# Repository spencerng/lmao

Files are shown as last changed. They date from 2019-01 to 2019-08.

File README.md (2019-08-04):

# Laundry Manager and Optimizer

The Laundry Manager and Optimizer was envisioned as an Internet of Things hamper that recognizes the laundry symbols (instructions) on clothing tags. It then sorts clothing articles into one of four sections so users can easily wash the right types of clothes together, thus preventing wear-and-tear.

Built by [Spencer Ng](https://github.com/spencerng) and [Kevin Tang](https://github.com/icevin) for their senior capstone project at the Middlesex County Academy for Science, Mathematics, and Engineering Technologies. [The project's prototype](https://devpost.com/software/load-optimization-assistance-device) was a Top 30 Hack winner at PennApps XVIII.

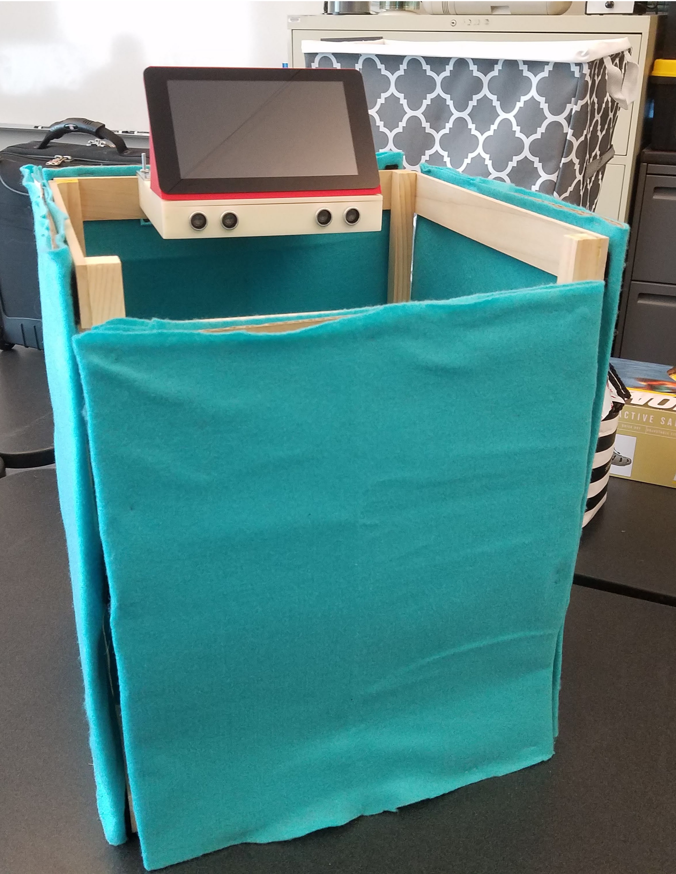
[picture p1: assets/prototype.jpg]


### Project specifications

**Hardware used**

* 3D-printed base and lid
* Ultrasonic sensors
* Raspberry Pi 3
* 7" touchscreen
* Raspberry Pi Camera Module V2
* Wood and cardboard frame for hamper prototype

**Software**

* Python 3 application developed for Raspberry Pi
* GUI built on Qt framework
* Symbol recognition done with OpenCV

### Additional links

* [Product manual with diagrams/screenshots](./assets/manual.pdf)
* [Initial design review with specifications](./assets/design-review.pdf)
* STL files
  * [Base](./assets/base.stl)
  * [Lid](./assets/lid.stl)
  * [Conceptual model](./assets/conceptual-model.stl)

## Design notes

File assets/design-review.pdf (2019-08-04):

# Laundry Manager and Optimizer (LMaO) Marking Period 1 Design Review & Deliverables

### Spencer Ng & Kevin Tang Electrical & Computer Engineering Technologies Middlesex County Academy

## Contents

1 Senior project proposal agreement | 2
2 Conceptual diagrams | 4
3 Block diagram | 10
4 Design specifications | 11
5 Gantt Chart | 14
6 Roles and responsibilities | 17
7 Bill of materials | 18
8 Risk factors and contingency plans | 19
9 Testing plans | 19
10 Patent search findings | 20
11 Acknowledgements and resources | 20

1

# l I I c1=t,sMET

L\tAD:E I!\ TrlE t:s.. t\

### Senior Project lnnovation

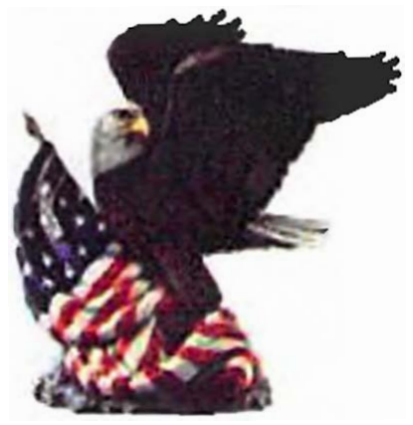
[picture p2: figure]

# lnvention title: Laundry Manager and Optimizer (LMaO) Instructor Name: Mr. E. Paterno Instructor Approval: f e Student Name: Spencer Ng Student Signature: ------- .h Student Name: Kevin Tang Student Signature: &w: ______ _ Problem to be addressed:

# Team No. 6

Date: to/ev/(¡ --¡,+---,---=---

# Date: / (J /¡ (J / l f

# Date: _1 (J

....J

/
'----

1 u---'-

/ 1
_

# ( __ _

Laundry tags convey important washing instructions for clothes in the form of standardized,

# universal laundry symbols. However, this system fails to accommodate users who may not have the time or knowledge to decode the symbols. Consequently, many individuals use the wrong cleaning products or machine settings, leading to unnecessary washing, energy

waste, and wear-and-tear.

lnnovation description: The Laundry Manager and Optimizer (LMaO) is an Internet of Things (loT) smart laundry system that scans the laundry symbols on tags using computer vision and machine learning technology. This information is uploaded to the Cloud, where it communicates with other LMaOs in the same household or living facility, allowing groups to Manage and Organize

loads quickly and determine the correct settings for each of their loads.

# lnnovation features: The LMaO can: - Sean ISO laundry care symbols on standard laundry tags usíng computer vision and machine learning technology

Senior project proposal agreement | Laundry Manager and Optimizer

- Connect multiple LMaOs for any user group to the cloud via Wi-Fi
- Automatically alert users when the attached hamper is full
- Provide user-friendly laundering instructions vía a touchscreen
- Reduce energy consumption while optimizing laundry loads

## lnnovation operation:

To place an article of clothing into the LMaO, the user locates the tag and places it in the scanning area of the LMaO. The LMaO then identifies the symbols and prompts the user via the touchscreen to drop the article into one of severa! hamper areas. When the LMaO(s) have reached capacity, or if the user indicates they wish to do their laundry (via the touchscreen of any linked LMaO), the user is provided with the recommended washer and dryer settings for each load and a list of articles of clothíng to wash.

## Required technologies:

Hardware | Software
Raspberry Pi (Single Board Computer) | OpenCV with Python
Raspberry Pi Camera | TensorF/ow
Raspberry Pi Touchscreen | Google C/oud P/atform (Firebase Server)
AC Power Circuitry | Wi-Fi

## Proposed customers:

- Washing or dryíng machine companies who wish to promete energy efficiency and assist users in determining the correct settings to use far their machines

lnvention title: Laundry Manager and Optimizer (LMaO)

Instructor lnitials: ----'-' --"'-/( _? __ _ Student lnitials: __ 5._._l\J_---- 1 Student lnitials: __ 'Í.._,_T ____ _ | Team No. 6
| Date: __ l

# ,1-0_/_v/Í_/_cY __

| Date: _1 ()) --1

, Ú
| ,_.. /_ fY ....:c.. /¡_ ( __ Date: __L ó..;_/_¹ l_· _( ,_i __ _
Senior project proposal agreement | Laundry Manager and Optimizer

## 7” Touchscreen Display

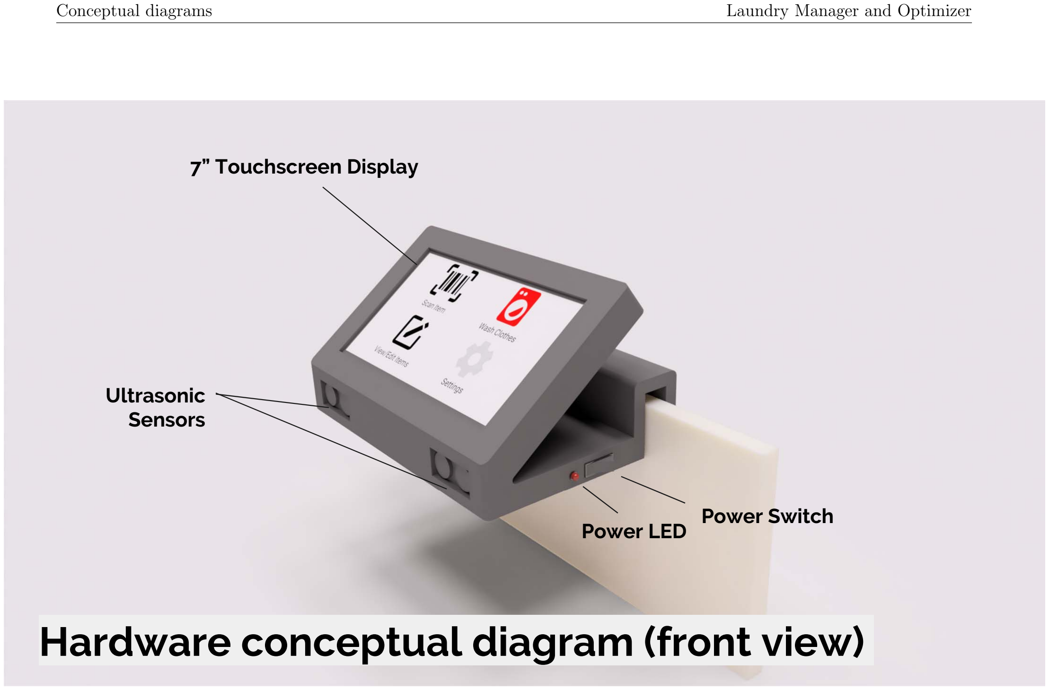
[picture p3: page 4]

Hardware conceptual diagram (front view).

## Power Switch Power LED

## Ultrasonic Sensors

Conceptual diagrams | Laundry Manager and Optimizer

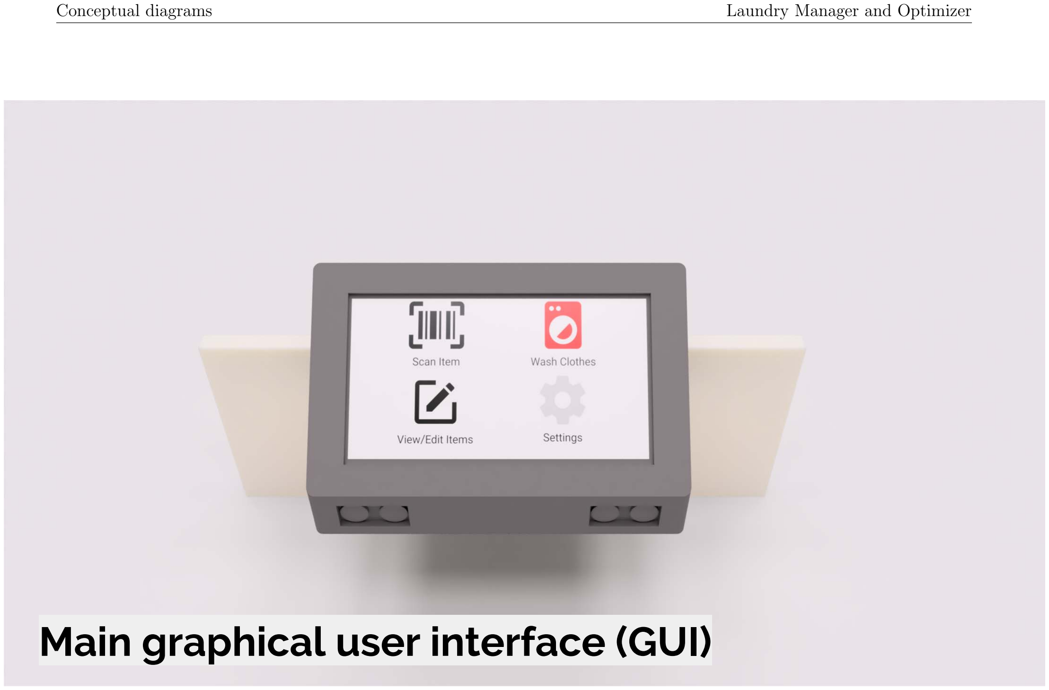
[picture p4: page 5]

# Main graphical user interface (GUI)

Conceptual diagrams | Laundry Manager and Optimizer

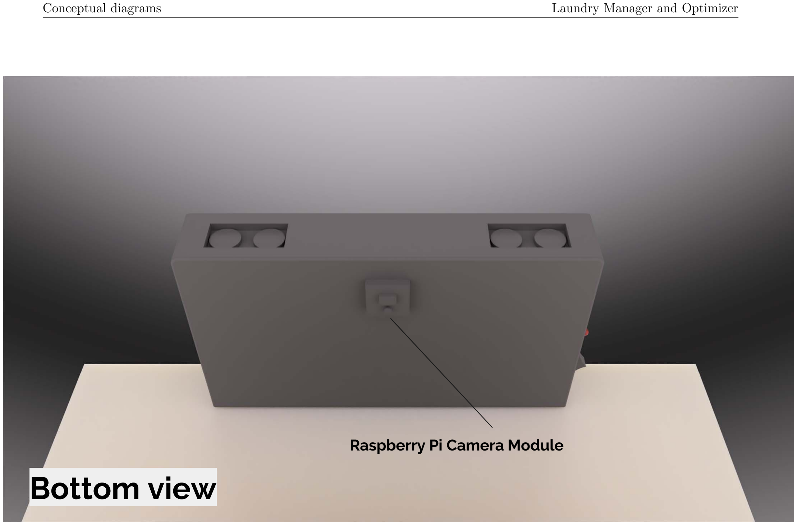
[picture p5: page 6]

# Bottom view

## Raspberry Pi Camera Module

Conceptual diagrams | Laundry Manager and Optimizer

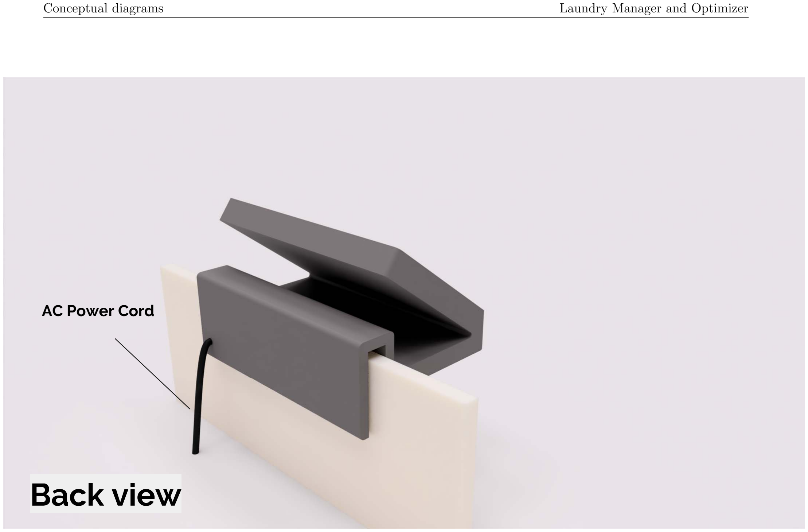
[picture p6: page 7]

# Back view

## AC Power Cord

Conceptual diagrams | Laundry Manager and Optimizer

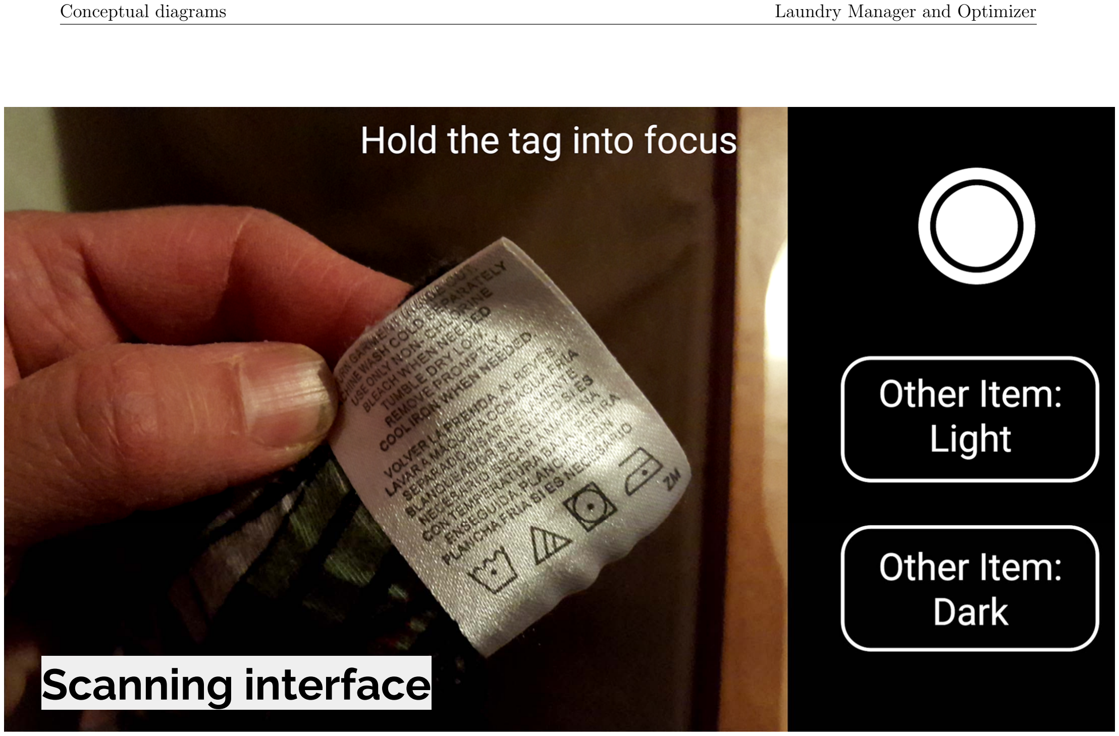
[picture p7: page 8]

# Scanning interface

Conceptual diagrams | Laundry Manager and Optimizer

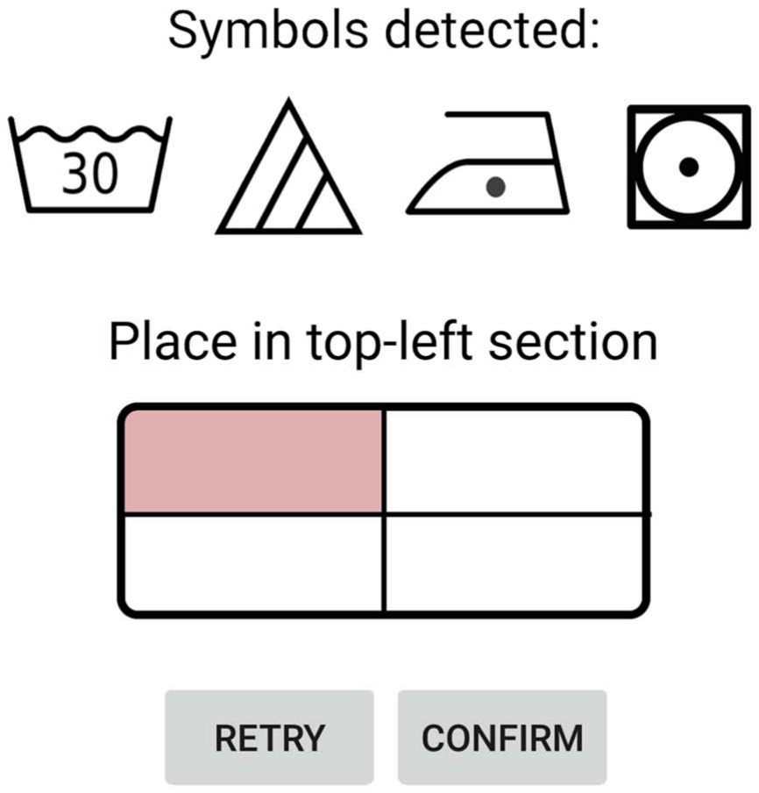
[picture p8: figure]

# Confirmation screen

Conceptual diagrams | Laundry Manager and Optimizer

## Block Diagram

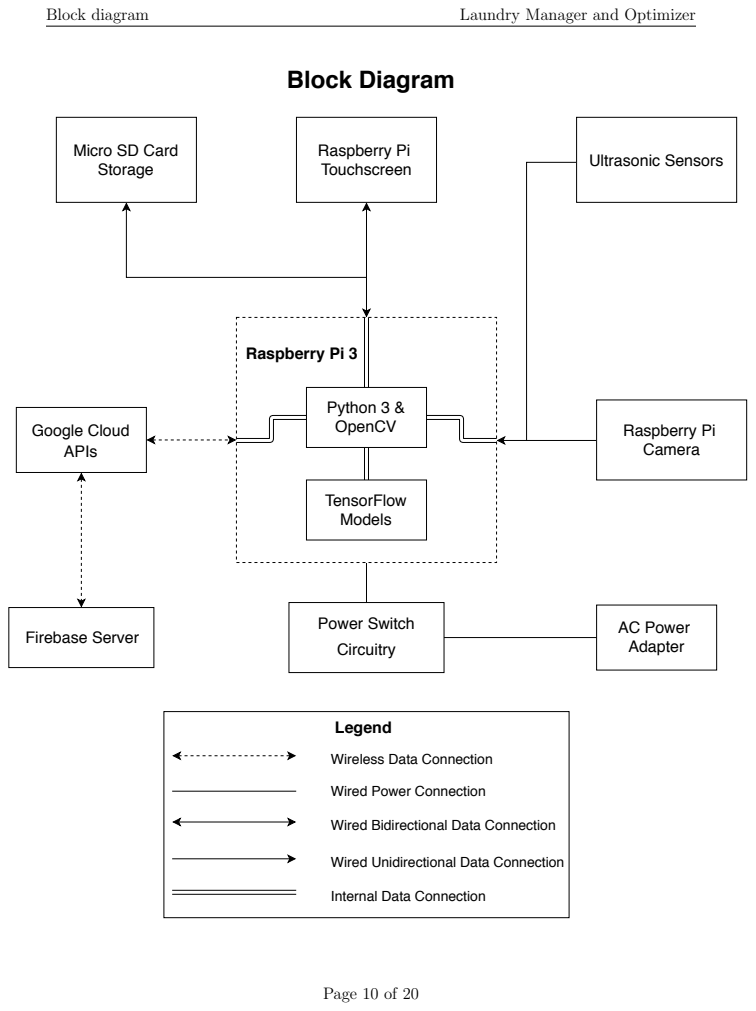
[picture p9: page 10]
Raspberry Pi Camera; Firebase Server; Google Cloud APIs; AC Power Adapter; Power Switch; Circuitry; Raspberry Pi 3; Legend; Python 3 & OpenCV; TensorFlow Models; Block diagram; Laundry Manager and Optimizer

Micro SD Card
Storage

Ultrasonic Sensors Raspberry Pi
Touchscreen

Wireless Data Connection

Wired Power Connection

Wired Bidirectional Data Connection

Wired Unidirectional Data Connection

Internal Data Connection

Functional descriptions and requirements | Laundry Manager and Optimizer

## 4 Design specifications

### 4.1 Hardware requirements

Raspberry Pi 3

- Single-board computer that drives the camera, touchscreen, ultrasonic sensors, and power circuitry
- Reads from and writes to external micro SD card storage
- Connects to cloud services via Wi-Fi

Ultrasonic sensors

- Send distance data to Raspberry Pi via GPIO pins
- Consistently and accurately detect when any section of the hamper is full
- Has 3 mm accuracy and 300 cm range

Raspberry Pi touchscreen

- Displays graphical user interface
- Allows users to interact with menu items
- Connects to Raspberry Pi via DSI port
- Has 7” screen size and 800 x 480 px resolution for large, easy-to-use interface

Raspberry Pi camera

- Connects to Raspberry Pi via CSI port
- Clearly scans and focuses on laundry symbols when are held 1-3” underneath
- Has 8 MP resolution

Micro SD card

- Contains 32 GB of storage for operating system, Python scripts, and TensorFlow models

Power circuitry

- Wakes and shuts down the Raspberry Pi via a slide switch
- Contains RBG LED indicator that turns green when powered on, red when off
- Located on a 2-layer printed circuit board, approximately 1” x 2”

AC power adapter

- Converts 120V AC power to 5V DC to power the Raspberry Pi via micro USB

Functional descriptions and requirements | Laundry Manager and Optimizer

### 4.2 Software requirements

Python 3 & OpenCV

- Boots into an easy-to-navigate material design GUI created with the Tkinter library

– Contains submenus for tag scanning, washing loads, settings, and viewing/editing items

- Scanning submenu opens camera feed with a button to scan items

– Displays recognized symbols for the user to confirm

– Directs users to drop clothing article in the correct section, based on color and machine wash settings

– Contains manual override for socks and underwear; prompts user for color

- Settings submenu contains user account management (create account/change pass-word), LMaO nickname, and washer/dryer information (database with information on all models from major brands)
- View/edit submenu allows users to modify the number of items in the hamper
- Prompts users to do their laundry when any section of the hamper is detected as full

– Ultrasonic sensors detect objects within 14” (length of hamper) for a period of at least one (1) minute

- Wash submenu instructs users to remove and wash articles from each section separately, making note of special instructions (ironing a shirt in a load of T-shirts, hand wash, dry clean, etc.)

– Groups clothing with similar or identical washing requirements into a single wash load

– Combines clothes from linked LMaOs for optimization, as necessary

– Satisfies the washing requirements of at least 90% of the items in a load

– Provides instructions pertinent to the user’s washer and dryer model

- OpenCV library interfaces with stored TensorFlow models and detects presence of laundry symbols via contours and image filtering

TensorFlow models

- Trained with a set of over 200 close-up, labeled laundry symbol images
- Recognize machine wash, bleach, tumble dry, and ironing symbols with at least 90% accuracy when given a series of close-up, focused images of standard laundry tags

Functional descriptions and requirements | Laundry Manager and Optimizer

Firebase server

- Syncs with all LMaOs connected via Wi-Fi every five (5) minutes or when LMaOs are powered on
- Stores user account information: username and hashed/salted passwords
- Provides a list of all LMaOs linked a particular user accounts, identified by user-provided nickname
- Stores a list of clothing located in each section of an LMaO and the laundry symbols on their tags
- Updates when an item is scanned and placed into the hamper of the LMaO
- Deletes items from the database after they are washed

### 4.3 Mechanical requirements

LMaO packaging

- Contains Raspberry Pi, touchscreen, camera, ultrasonic sensors, AC adapter cord, and power switch circuitry in a 3D-printed box

– Touchscreen and ultrasonic sensors face outward, toward opposite edge of hamper

– Power switch printed circuit board soldered to the side of Raspberry Pi and is accessible by users

– AC adapter cord extends outward from the back

– Camera faces downward, into laundry hamper

- Held together by interlocking parts, Velcro, and screws and can withstand mild shaking
- Clamps onto the back edge of the laundry hamper without additional support
- Provides sufficient ventilation so the Raspberry Pi does not overheat

Laundry hamper

- Contains four (4) compartments of equal size for ease-of-use when removing clothes for different loads
- Supports the weight of the LMaO packaging on at least one (1) top edge
- Requires no additional support to stand up
- Approximately 14” x 14” x 23” in size with an open top; easily transportable

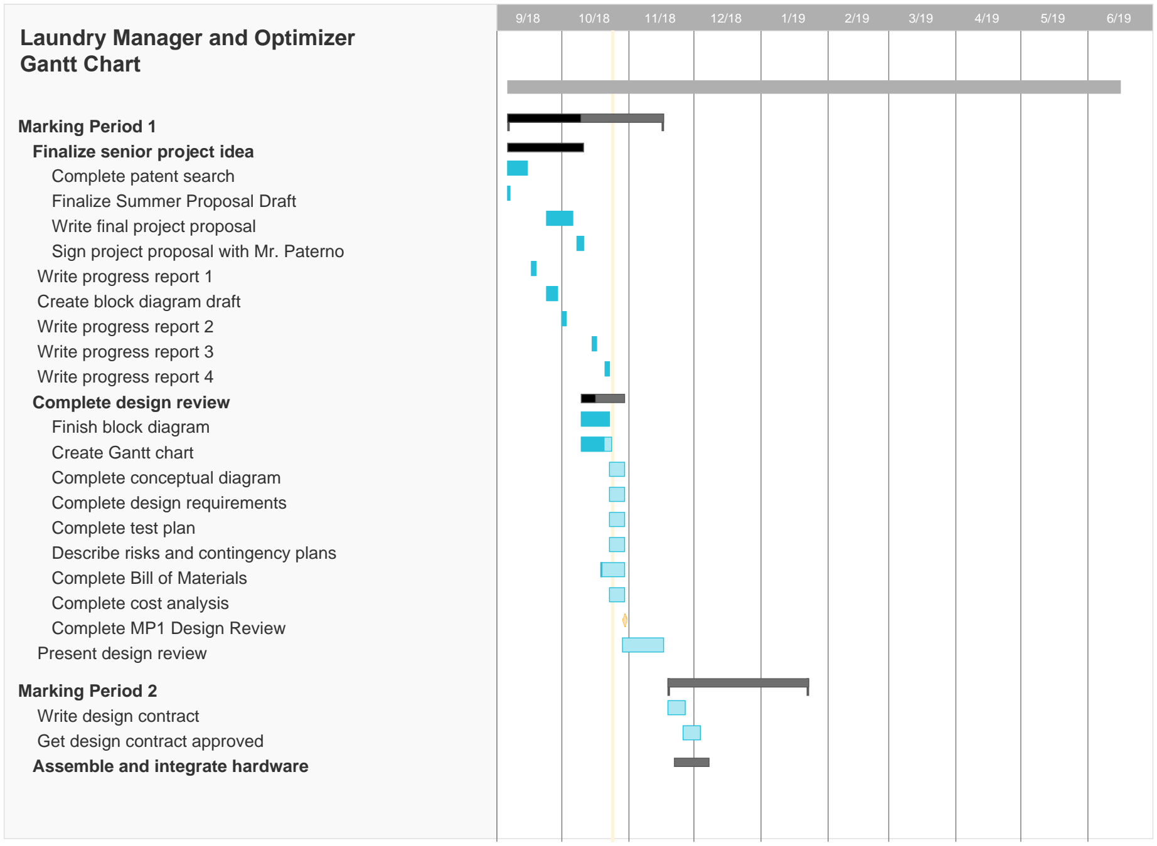
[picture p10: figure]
Laundry Manager and Optimizer Gantt Chart; Marking Period 1 Finalize senior project idea Complete patent search Finalize Summer Proposal Draft Write final project proposal Sign project proposal with Mr. Paterno Write progress report 1 Create block diagram draft Write progress report 2 Write progress report 3 Write progress report 4 Complete design review Finish block diagram Create Gantt chart Complete conceptual diagram Complete design requirements Complete test plan Describe risks and contingency plans Complete Bill of Materials Complete cost analysis Complete MP1 Design Review Present design review; Marking Period 2 Write design contract Get design contract approved Assemble and integrate hardware

9/18 | 10/18 | 11/18 | 12/18 | 1/19 | 2/19 | 3/19 | 4/19 | 5/19 | 6/19
Gantt chart | Laundry Manager and Optimizer

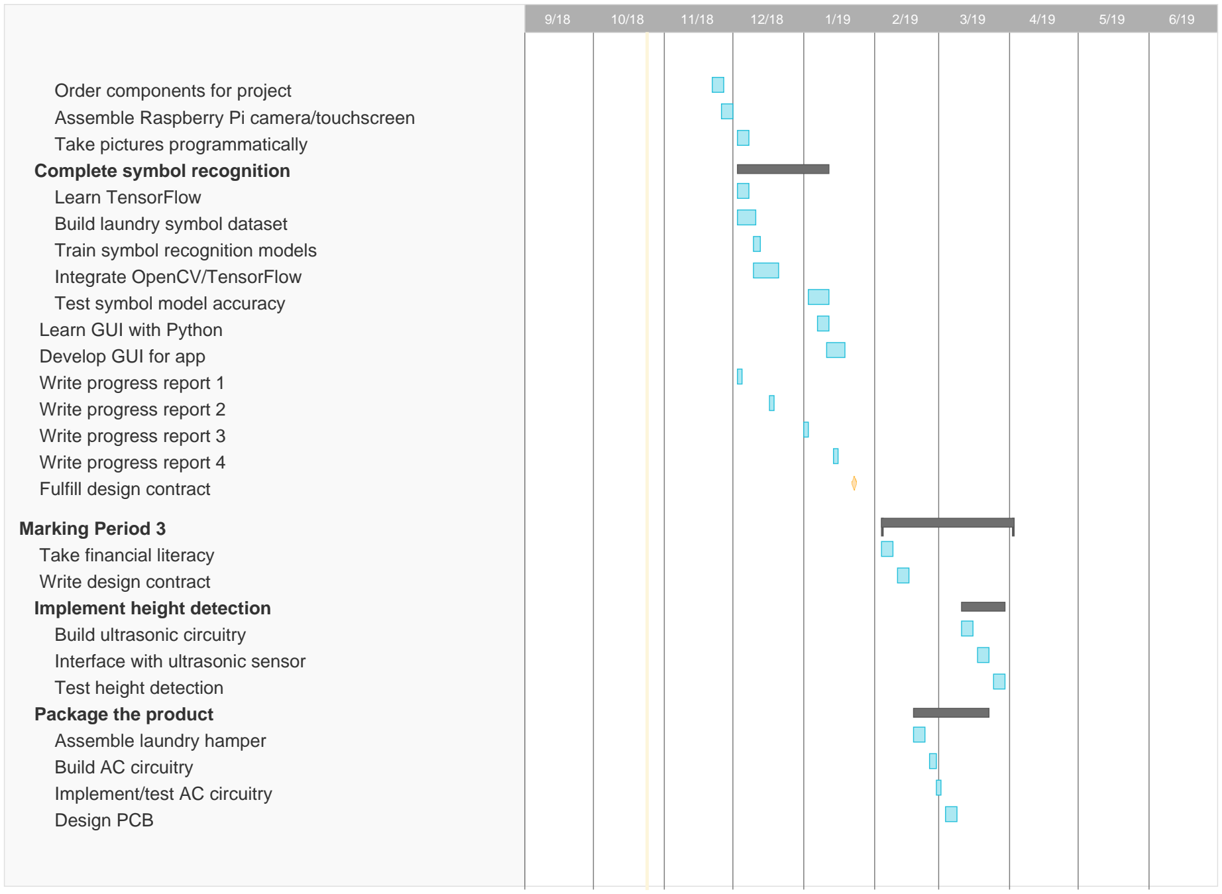
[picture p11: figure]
Order components for project; Take pictures programmatically Complete symbol recognition Learn TensorFlow Build laundry symbol dataset Train symbol recognition models Integrate OpenCV/TensorFlow Test symbol model accuracy Learn GUI with Python Develop GUI for app Write progress report 1 Write progress report 2 Write progress report 3 Write progress report 4 Fulfill design contract; Marking Period 3 Take financial literacy Write design contract Implement height detection Build ultrasonic circuitry Interface with ultrasonic sensor Test height detection Package the product Assemble laundry hamper Build AC circuitry Implement/test AC circuitry Design PCB

9/18 | 10/18 | 11/18 | 12/18 | 1/19 | 2/19 | 3/19 | 4/19 | 5/19 | 6/19

### Assemble Raspberry Pi camera/touchscreen

Gantt chart | Laundry Manager and Optimizer

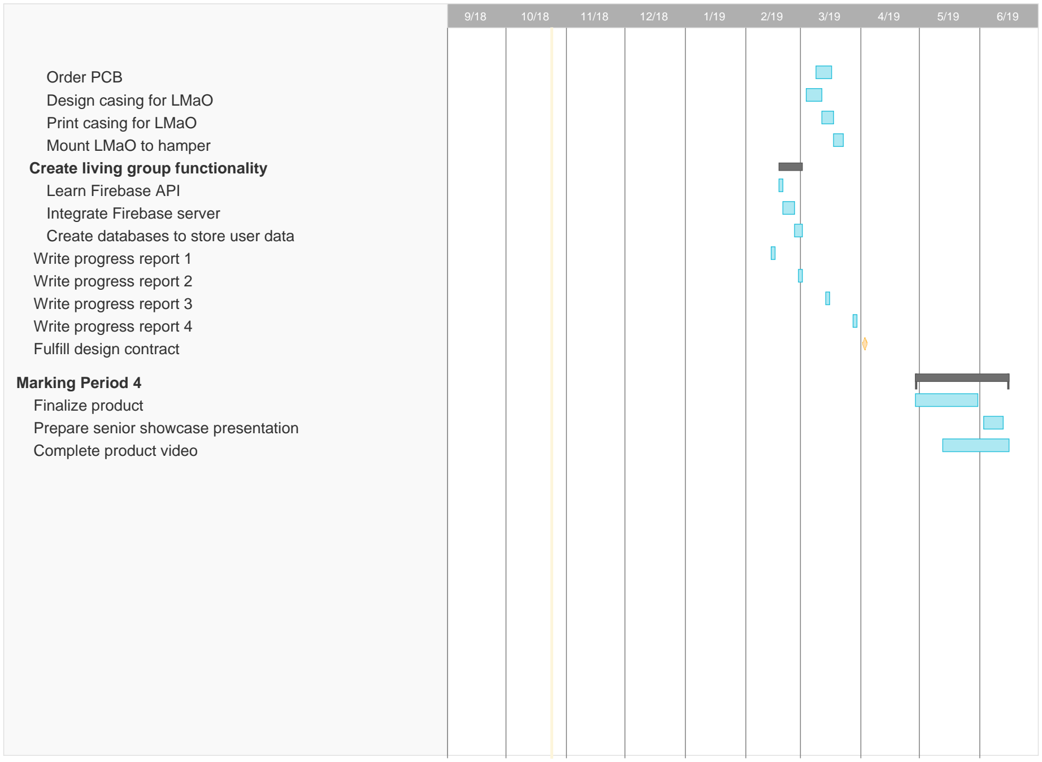
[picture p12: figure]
Order PCB Design casing for LMaO Print casing for LMaO Mount LMaO to hamper Create living group functionality Learn Firebase API Integrate Firebase server Create databases to store user data Write progress report 1 Write progress report 2 Write progress report 3 Write progress report 4 Fulfill design contract; Marking Period 4 Finalize product Prepare senior showcase presentation Complete product video

9/18 | 10/18 | 11/18 | 12/18 | 1/19 | 2/19 | 3/19 | 4/19 | 5/19 | 6/19

Powered by TCPDF (www.tcpdf.org)

Gantt chart | Laundry Manager and Optimizer

Team roles | Laundry Manager and Optimizer

## 6 Roles and responsibilities

Team responsibilities

- Write project proposal and design requirements
- Create Gantt chart, block diagram, and bill of materials
- Write design contracts for each marking period
- Perform integration and system testing
- Write progress reports and document progress in engineering notebook
- Produce final video detailing product design

Spencer - software development

- Interface camera with Python
- Integrate OpenCV with TensorFlow models
- Create the GUI with Python
- Interface ultrasonic sensors with Python
- Create Firebase server to store user data and sync with Python
- Edit product video

Kevin - hardware design and machine learning

- Design, 3D-print, and assemble product casing and mounting solution
- Design and build power circuitry
- Manage component acquisition
- Build laundry symbol image dataset
- Train TensorFlow models
- Design and order printed circuit board

Item Number | Number Part | Part Description | Designation Reference | Primary Source | Secondary Source | Lead Time | Cost | Unit | Total Cost
RASPBERRYPI 3-MODB | 51AC3219 | Raspberry Pi 3 B+ Motherboard | RPI | https://goo.gl/N6efV7 | https://www.adafruit.com/product/3775 | 1 week | $42.50 | 1 | $42.50
N/A | N/A | Raspberry Pi 7" Touchscreen Display | TCH | https://goo.gl/1e8jwp | https://www.adafruit.com/product/2718 | 1 week | $78.63 | 1 | $78.63
RPI-CAM-V2 | N/A | Raspberry Pi Camera Module | CAM | https://goo.gl/ePeF2F | https://www.adafruit.com/product/3099 | 1 week | $26.51 | 1 | $26.51
SDSQUNC-032G-GN6MA | N/A | 32 GB microSD Card | MSD | https://goo.gl/gcbZgT | https://goo.gl/WUdMCq | 1 week | $9.81 | 1 | $9.81
N/A | N/A | Printed Circuit Board | PCB | https://jlcpcb.com | https://www.pcbway.com/ | 2-4 weeks | $20.00 | 1 | $20.00
N/A | N/A | Raspberry Pi AC Adapter | AC | https://goo.gl/PSC9YC | https://goo.gl/dQE9xz | 1 week | $10.61 | 1 | $10.61
HC-SR04 | EL-SM-001 | Ultrasonic Sensor (x5) | US | https://goo.gl/KaqhEV | https://www.sparkfun.com/products/13959 | 1 week | $10.39 | 1 | $10.39
AQ-NON005 | N/A | Foldable Laundry Hamper | LH | https://goo.gl/SdDxgj | https://goo.gl/bhfSYd | 1 week | $18.64 | 1 | $18.64
| | | | | | | | Grand Total | $217.09

# Bill of Materials

Bill of Materials | Laundry Manager and Optimizer

Risk factors and testing | Laundry Manager and Optimizer

## 8 Risk factors and contingency plans

Risk factors | Contingency plan
Image recognition with TensorFlow may not be sufficiently accurate | Use alternate machine learning platforms (Google AutoML, Microsoft Azure CV); train models with a larger dataset
Mounting the LMaO on the hamper may be difficult | Create support for LMaO casing within the hamper or improve hamper backing to endure a greater load
Space and load constraints when designing case for hardware | Reposition components to distribute load (place touchscreen to the side of the hamper, place clamps toward the middle of the casing, etc.)
Ultrasonic sensors may experience bounceback | Programatically debounce the ultrasonic sensors; use depth sensing with an additional camera and OpenCV

## 9 Testing plans

### 9.1 Unit testing

- Raspberry Pi: connect with PC and run Python 3 scripts independently
- Camera: capture images programmatically
- TensorFlow: correctly identify symbols in pre-existing images with trained models on a PC
- Ultrasonic sensors: accurately detect range when connected to a PC
- Power circuitry: lights up when 5V is applied and switch is turned
- Firebase: send and receive data through a PC using REST APIs
- Touchscreen: connect with the Raspberry Pi and ensure touch inputs are registered correctly

### 9.2 Integration testing

- Programmatically process images taken with the RPi camera on the Raspberry Pi using OpenCV and TensorFlow, ensuring at least 90% accuracy for 20 images
- Navigate Python GUI through the Raspberry Pi touchscreen
- Communicate with Google Cloud and sync data with Firebase from RPi, then verify by going to Firebase’s web interface to modify and view data
- Accurately determine distance with ultrasonic sensors with Raspberry Pi housed in casing
- Reliably turn on and safely turn off Raspberry Pi at least five (5) times with power switch

Risk factors and testing | Laundry Manager and Optimizer

### 9.3 System testing

- Power all components
- Identify pertinent laundry information accurately
- Ensure clothing items and LMaOs associated with a particular user sync to Firebase
- Instruct user to separate into proper loads, incorporating data from other LMaOs
- Detect when the hamper is full with clothes, repeating with each of the four (4) sections

## 10 Patent search findings

US 571555

- ”Laundry system. . . for reading laundering instructions contained in an electronic tag while the item is in a laundry machine”
- LMaO operates outside of a laundry machine and does not require any electronic tags to operate - just the standard laundry tag

US 5388299

- “Reading washing information on mediums attached to clothes, checking possibility of mixed washing with the stored info”
- LMaO offers cloud syncing for entire living group and is not limited to the settings on a single washing machine or dryer

## 11 Acknowledgements and resources

- Mr. Enzo Paterno, Electrical and Computer Engineering Technologies instructor
- US 5715555: https://patents.google.com/patent/US5715555
- US 5388299: https://patents.google.com/patent/US5388299
- Laundry symbol guide: http://www.textileaffairs.com/lguide.htm
- Block diagram created with Draw.io
- Conceptual diagrams created with Autodesk Fusion 360 and Adobe Photoshop
- Gantt chart created with TeamGantt
- Bill of materials created with Microsoft Excel

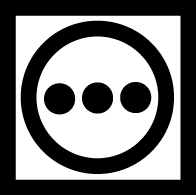
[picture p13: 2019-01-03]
img/tumbledry_high.png

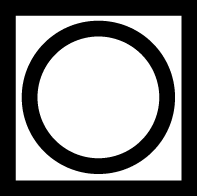
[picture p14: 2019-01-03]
img/tumbledry_ok.png

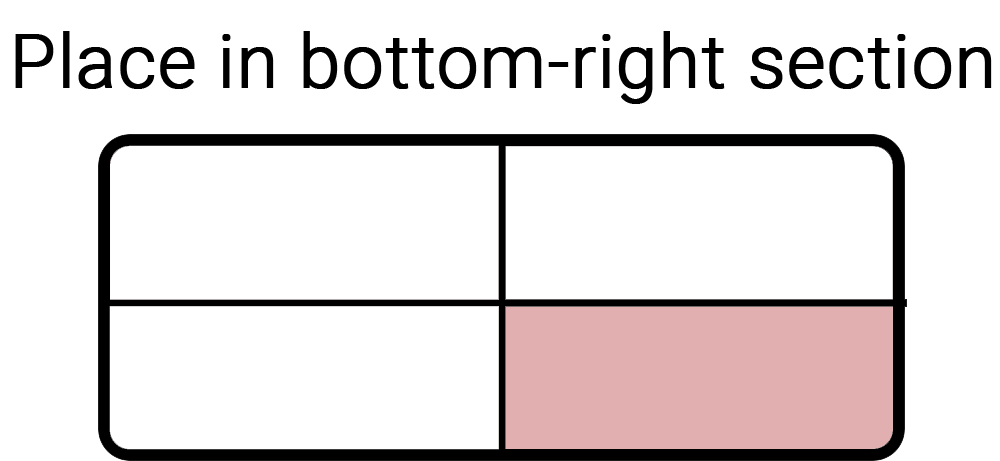
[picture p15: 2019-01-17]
img/place_br.png

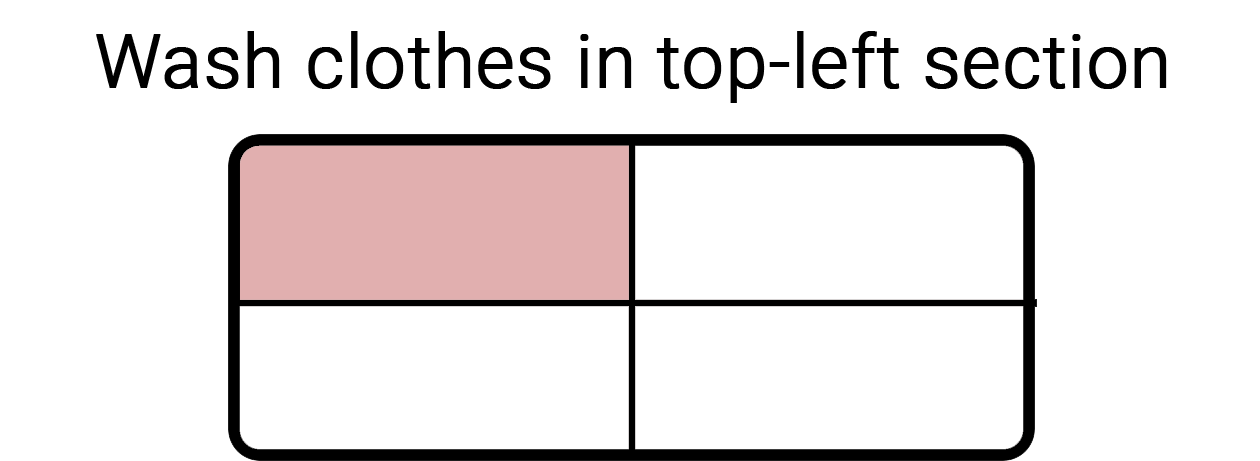
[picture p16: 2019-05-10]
img/wash_tl.png

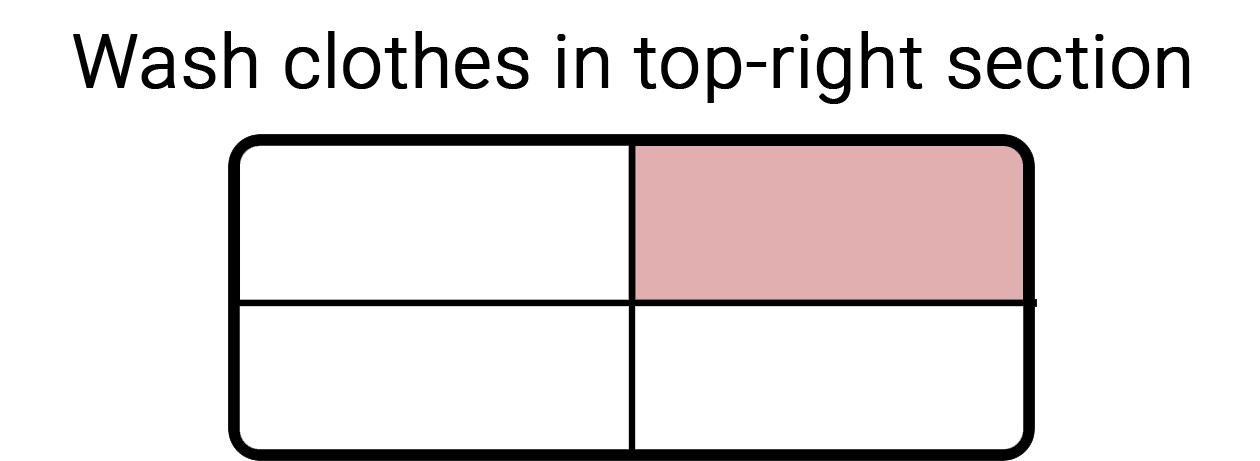
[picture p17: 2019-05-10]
img/wash_tr.png

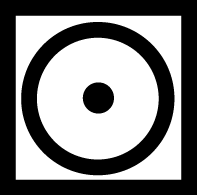
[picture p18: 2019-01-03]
img/tumbledry_low.png

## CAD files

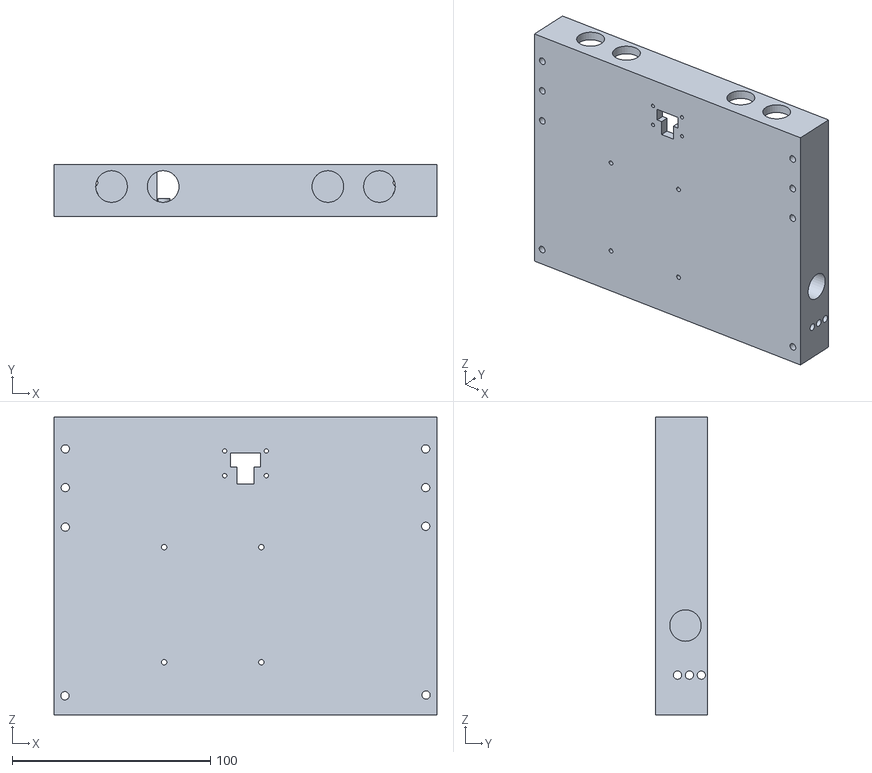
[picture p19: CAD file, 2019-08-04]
assets/base.stl
193.0 x 26.0 x 150.0

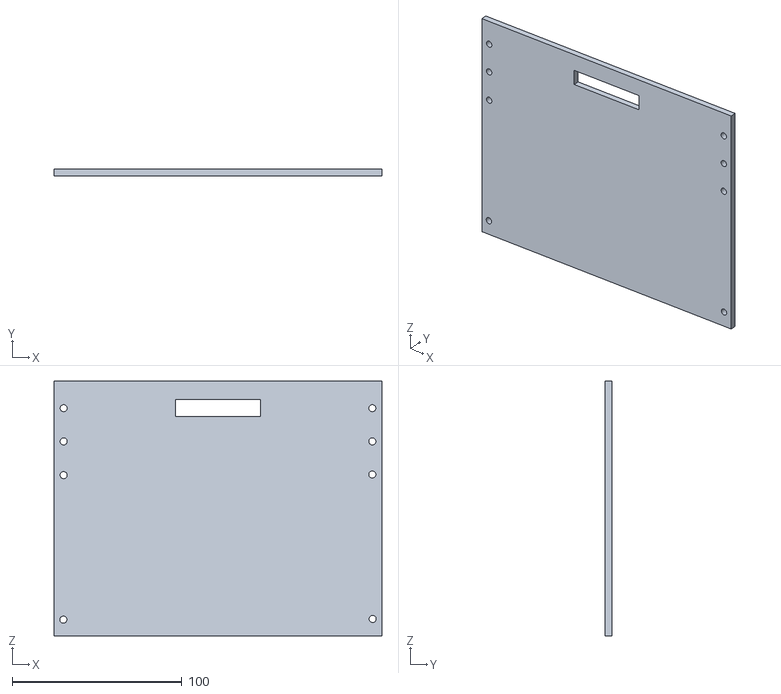
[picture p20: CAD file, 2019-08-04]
assets/lid.stl
193.0 x 4.00 x 150.0

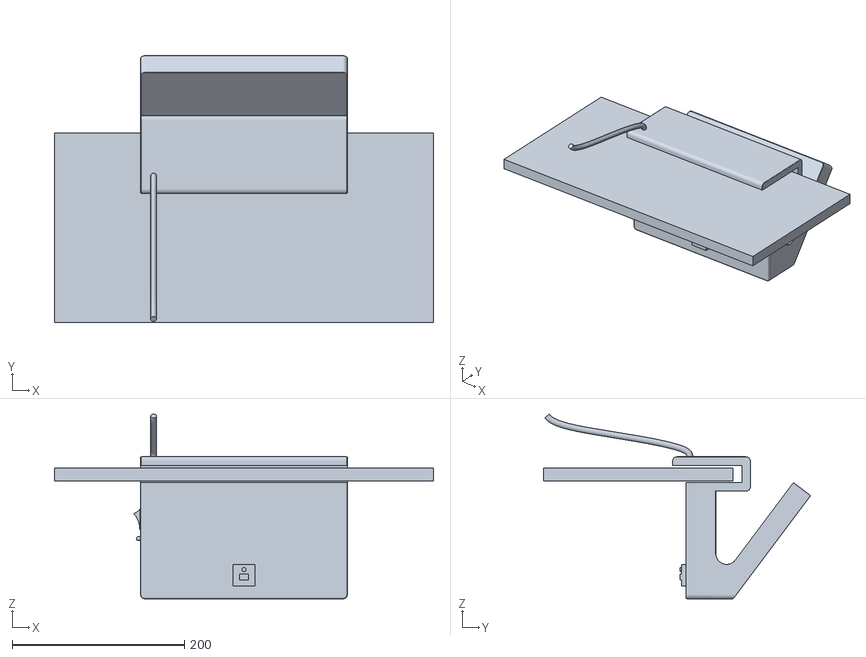
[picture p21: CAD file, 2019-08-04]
assets/conceptual-model.stl
440.0 x 309.6 x 214.5

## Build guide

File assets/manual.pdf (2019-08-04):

# Laundry Manager and Optimizer

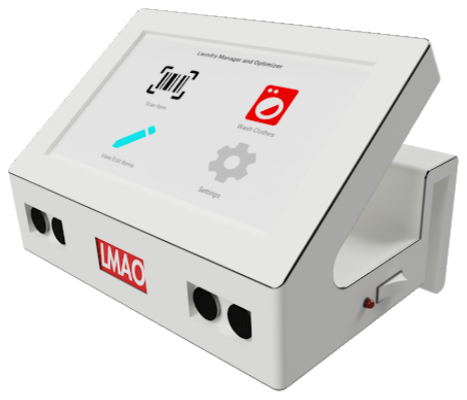
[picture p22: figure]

# Operations Manual

## Introduction

The Laundry Manager and Optimizer (LMaO) is a smart laundry hamper system that detects and scans laundry symbols on clothing tags, organizes items accordingly, and instructs users on the optimal laundry washing settings when the hamper fills up. It can be used by a single user or linked to a system of multiple LMaOs for maximum energy savings. This manual describes how to operate and use all the features of your LMaO.

## Product Overview

## What’s in the Box

Your product comes with the following parts:

- One (1) Laundry Manager and Optimizer device (left)
- One (1) USB-AC adapter (right): Provides power to the LMaO device.

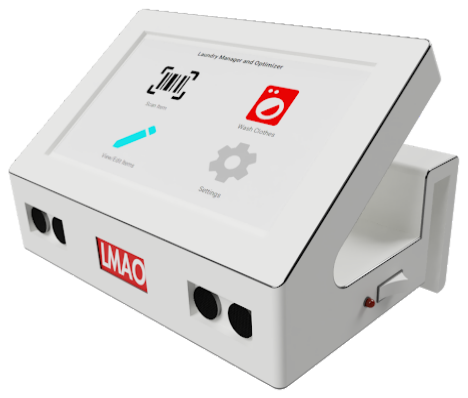
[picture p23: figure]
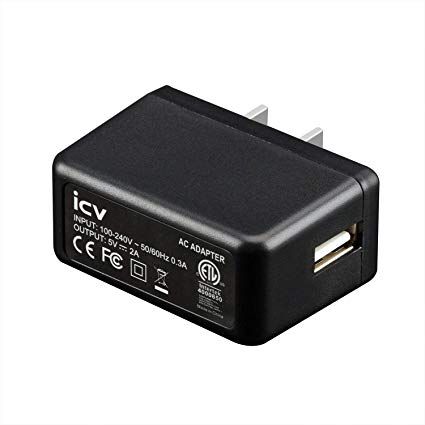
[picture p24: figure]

The following components are part of the main LMaO device:

- One (1) 7” touchscreen display: Use this to interact with the main LMaO software.
- Two (2) ultrasonic sensors: These detect when the hamper attached to the LMaO is full.
- One (1) power switch: Slide the power switch to turn the LMaO on and off.
- One (1) LED indicator: Possible states include:
- No color: Power is currently not provided to the LMaO
- Red: Power is provided to the LMaO, but the LMaO is not turned on
- Green: The LMaO is turned on

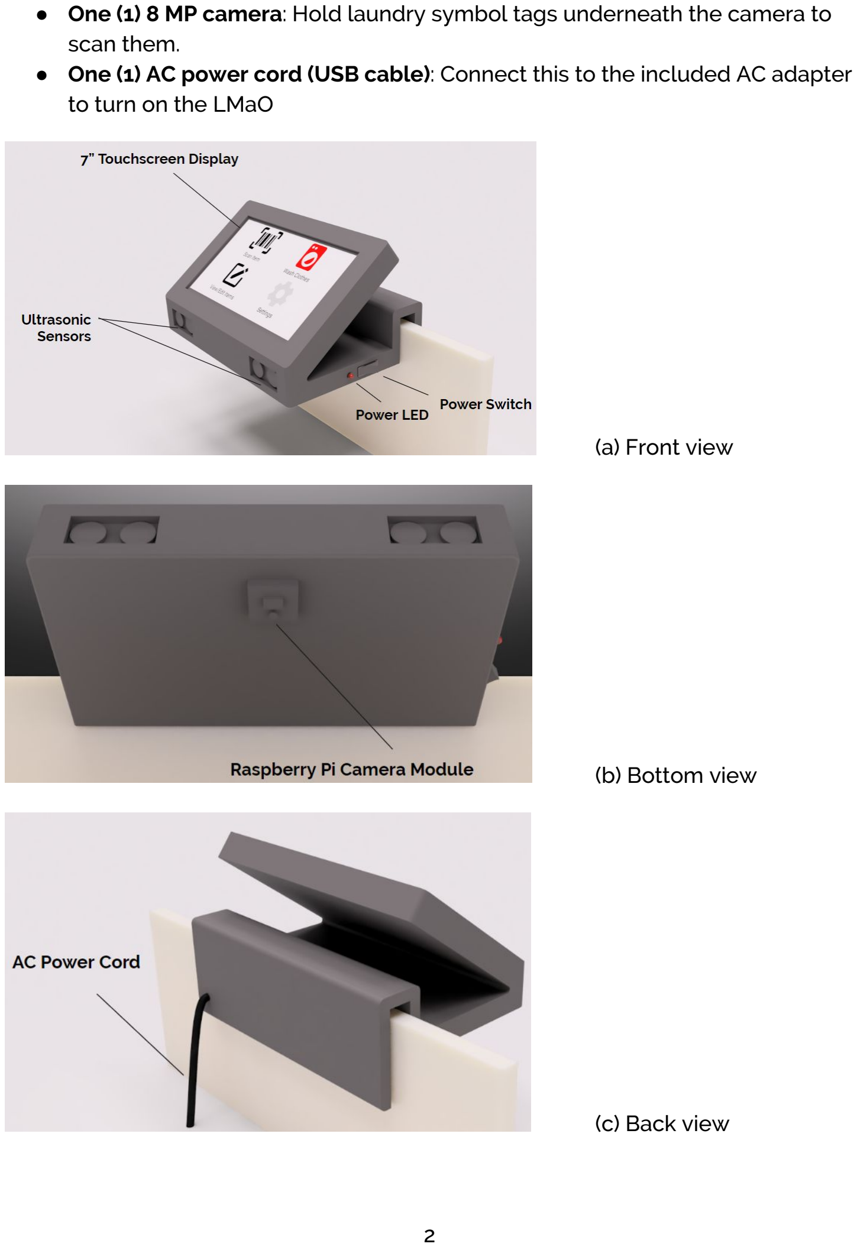
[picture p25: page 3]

- One (1) 8 MP camera: Hold laundry symbol tags underneath the camera to scan them.
- One (1) AC power cord (USB cable): Connect this to the included AC adapter to turn on the LMaO
(a) Front view
(b) Bottom view
(c) Back view

## Main Menu

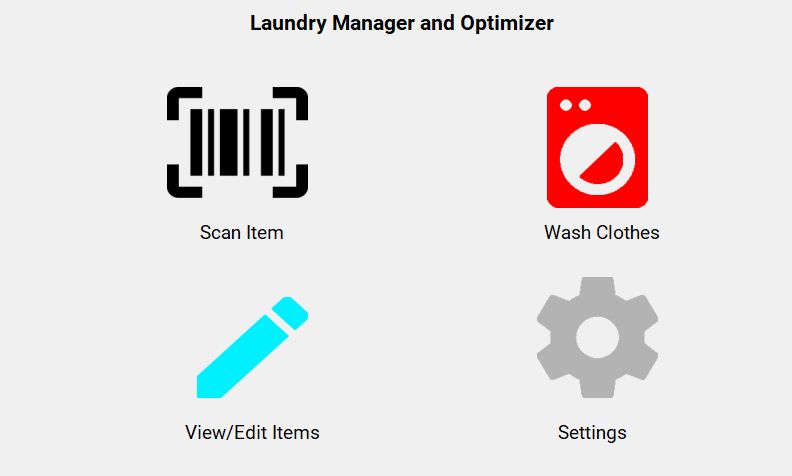
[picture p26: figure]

The main menu of the LMaO contains four submenus:

- Scan Item: Displays the Scan Menu, where you can scan laundry tags and add new items to the LMaO.
- Wash Clothes: Displays instructions to wash all the clothes currently in the LMaO.
- View/Edit Items: View and delete items currently in the LMaO.
- Settings: Adjust device brightness, manage data, and change laundry symbol detection method.

## Getting Started

1. Identify which laundry hamper you’ll be using with the LMaO.
2. Ensure that the back of the hamper is sturdy enough to support the weight of the LMaO by carefully sliding the LMaO downwards onto the back face of the hamper.
3. Once the LMaO is securely attached, attach the USB cable from the main LMaO device to the USB-AC adapter.
4. Plug the USB-AC adapter into a nearby outlet and connect the LMaO’s power cord to the adapter.
5. After sliding the power switch, LMaO will turn on and is immediately ready for use.

## Wi-Fi Setup

In addition to the AC power you connected above, the LMaO also supports an optional Wi-Fi connection to sync clothing articles across multiple LMaO devices.

To connect, tap the Wi-Fi icon in the taskbar at the top of the screen and follow the on-screen instructions to connect to a network.

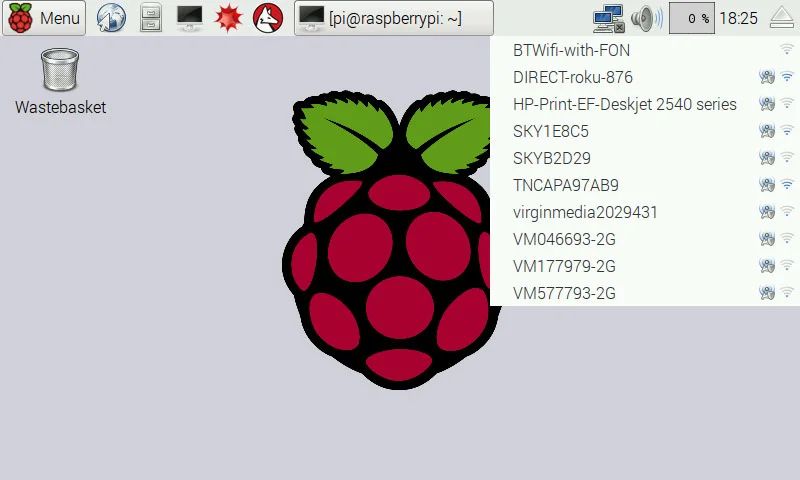
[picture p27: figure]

## Adding Clothing Articles

Begin adding new clothing articles to the LMaO by opening the Scan Menu from the Main Menu.

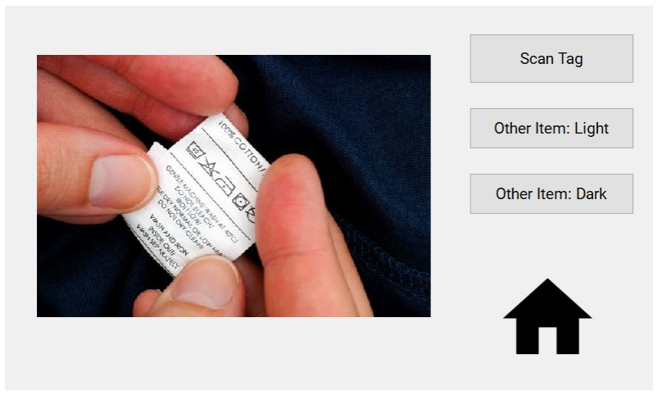
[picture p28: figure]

If the clothing article has a laundry tag:

1. Hold the laundry tag (pictured above) below the camera at the bottom of the LMaO.
2. Once the tag’s symbols are in focus, press the “Scan Tag” button.

3. After several seconds, the laundry symbols recognized by the LMaO will display on screen.

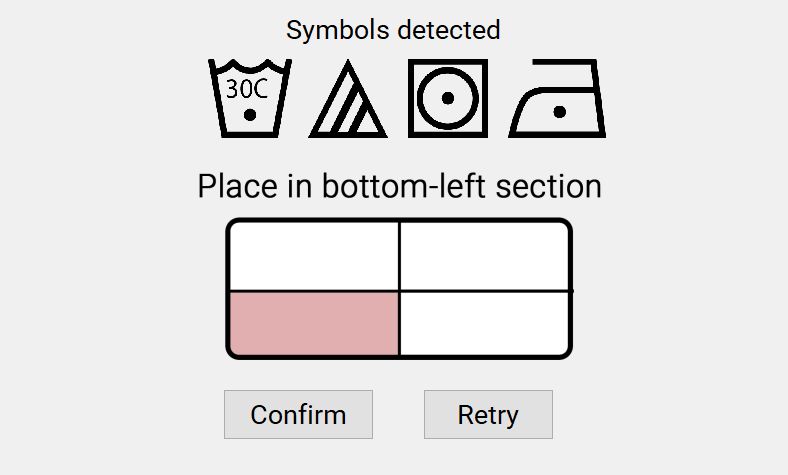
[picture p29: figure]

4. If the displayed symbols match the ones on the laundry tag, place the clothing article in the hamper section specified by the LMaO, then press the “Confirm” button.
5. If the displayed symbols do not match, press the “Retry” button to scan the laundry tag again.

If the clothing article (e.g. socks, underwear) does not have a laundry tag:

1. If the clothing article is light in color (i.e. white or light gray), press the “Other Item: Light” button. Otherwise, press the “Other Item: Dark” button.

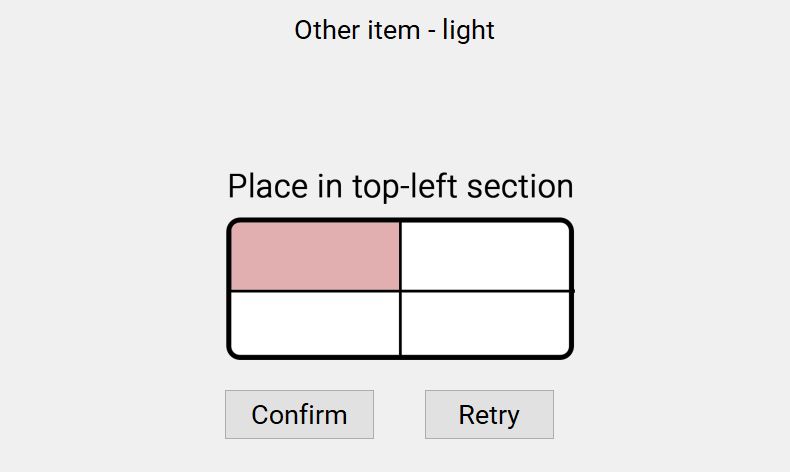
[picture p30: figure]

2. Place the clothing article in the hamper section specified by the LMaO, then press the “Confirm” button.

## Modifying Hamper Contents

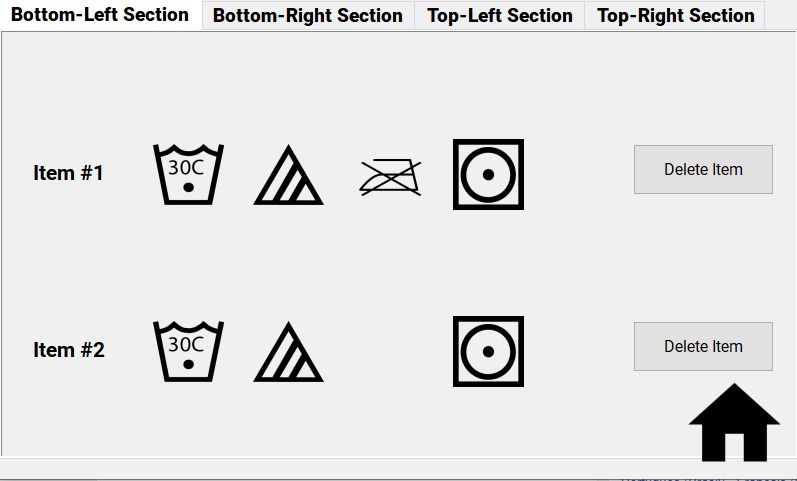
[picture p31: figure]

1. Open the “View/Edit Items” menu.
2. Select the appropriate tab to view clothing articles and their symbols in a section.
3. Click “Delete Item” to remove items that are physically removed from a section.

Note: The LMaO will automatically remove articles from this menu once they are washed.

## Washing Clothes

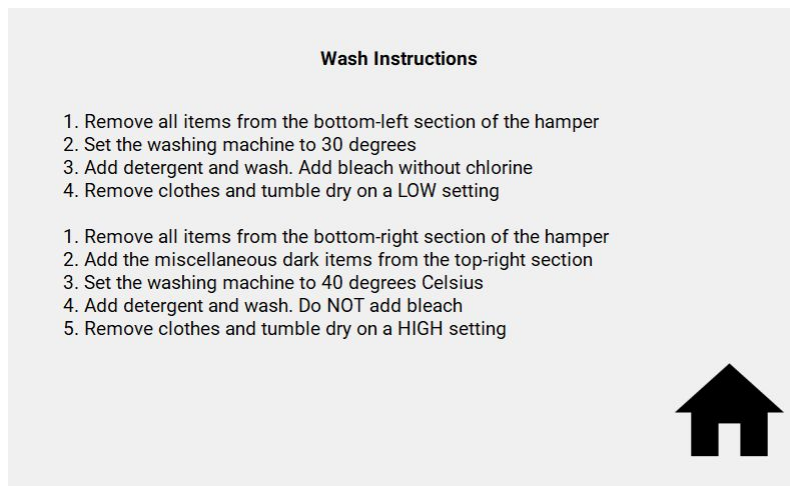
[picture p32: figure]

1. Open the “Wash Clothes” menu.

2. Remove items from the hamper and place them into the washing machine according to the on-screen directions.
3. Once all items for a load have been removed, the LMaO will tell you which settings you should use to wash those clothes.

## Special Features

## Overflow Detection

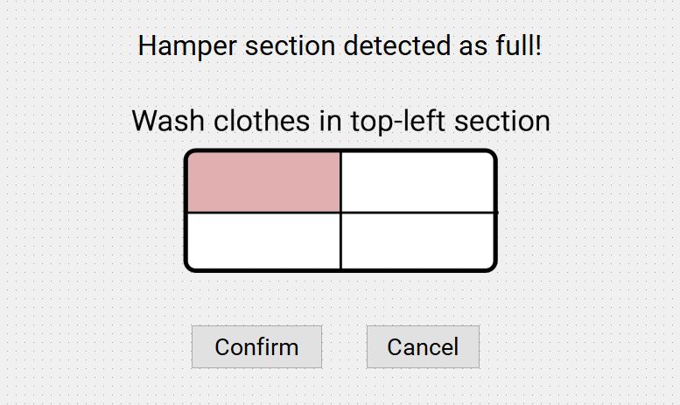
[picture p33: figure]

The LMaO automatically detects if any of the four hamper sections have been filled. Once it detects a full section, it will prompt you to wash the clothes in that section and will not allow any new clothes to be categorized into that section.

## Settings

Begin by opening the settings menu:

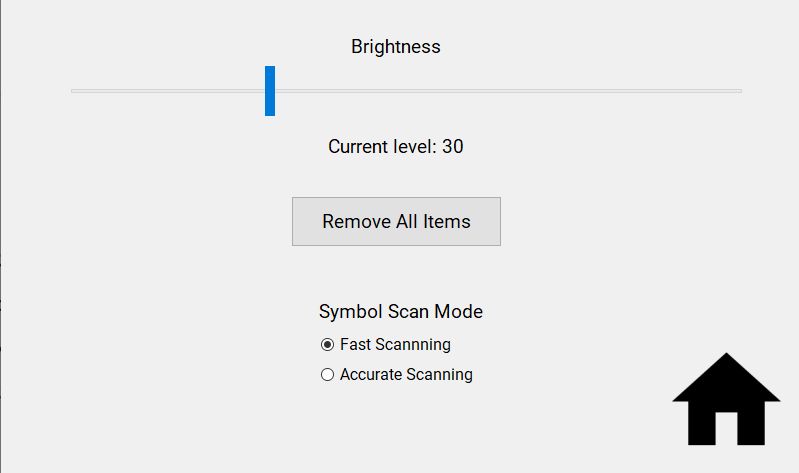
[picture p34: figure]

## Brightness

If needed, you can adjust the brightness of the LMaO’s screen using the slider at the top of the screen.

## Scan Modes

The LMaO can be configured to use one of two scanning modes: Fast Scanning or Accurate Scanning. Fast Scanning uses the LMaO’s on-board image recognition models, and is fairly accurate. However, if symbols on certain articles of clothing are not being recognized properly, the Accurate Scanning mode may be used. Accurate scanning uses the Internet to use more complex image recognition models.

## Data Reset

If you’d like to quickly reset all data, press the “Remove All Items” button to clear the LMaO’s memory.

## Troubleshooting

Issue | Possible Solution(s)
Screen does not turn on | Unplug the LMaO’s power cable, wait 5 seconds, then plug in the LMaO’s power cable

Ensure that the screen’s brightness is set sufficiently high in the Settings menu

Camera does not focus | Clean the camera module, located on the bottom of the LMaO
Overflow is not detected | Ensure that there are no objects blocking the ultrasonic modules at the front of the LMaO

## Technical Specifications

- 1.4GHz 64-bit quad-core CPU
- 1GB Ram
- 8MP Camera Module
- 2 x Ultrasonic Sensor Module
- 800 x 480 pixel 7” touchscreen

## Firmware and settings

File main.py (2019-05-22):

#!/usr/bin/python
from os import sys
from enum import Enum
from threading import Thread
import time
import cv2
import jsonpickle

from PyQt5.QtWidgets import *
from PyQt5.QtCore import Qt, QObject, pyqtSignal, QThread, QPoint
from PyQt5.QtGui import QPixmap

import mainmenu
import scanmenu
import confirmmenu
import settingsmenu
import vieweditmenu
import washpopup
import clothingeditwidget
import washmenu

PI_ACTIVE = True
CHEESE_ACTIVE = True
DATA_FILENAME = 'clothes.dat'
CURRENT_CLOTHES = {}

try:
    import picamera
    import picamera.array
    import rpi_backlight as backlight
    from ultrasonic import Ultrasonic
except ModuleNotFoundError as e:
    PI_ACTIVE = False

TRIG_LEFT = 23
ECHO_LEFT = 24

TRIG_RIGHT = 17
ECHO_RIGHT = 27

# Ultrasonic distance settings [cm]
# Adjusted for a 7" x 7" hamper, divided into 4 sections
TOP_MIN_DIST = 0.0
TOP_MAX_DIST = 7.4
BOTTOM_MIN_DIST = 7.5
BOTTOM_MAX_DIST = 20.0

# How often to check if the hamper is full [s]
REFRESH_TIME = 1.0

UI_INDEX = {
    'MAIN_MENU': 0,
    'SCAN_MENU': 1,
    'CONFIRM_SCREEN': 2,
    'SETTINGS_MENU': 3,
    'WASH_ITEMS_MENU': 5,
    'VIEW_EDIT_MENU': 6,
    'WASH_POPUP': 4,
}




class LaundrySymbols(Enum):

    OTHER_DARK = 0
    OTHER_LIGHT = 1
    BLEACH_NO = './img/bleach_no.png'
    BLEACH_NOCL = './img/bleach_nocl.png'
    TUMBLEDRY_H = './img/tumbledry_high.png'
    TUMBLEDRY_L = './img/tumbledry_low.png'
    TUMBLEDRY_OK = './img/tumbledry_ok.png'
    IRON_H = './img/iron_high.png'
    IRON_L = './img/iron_low.png'
    IRON_M = './img/iron_medium.png'
    IRON_NO = './img/iron_no.png'
    WASH_30 = './img/wash_30c.png'
    WASH_40 = './img/wash_40c.png'
    WASH_50 = './img/wash_50c.png'

class MainWindow(QMainWindow, mainmenu.Ui_MainMenu):

    def __init__(self):
        super(self.__class__, self).__init__()
        self.setupUi(self)
        self.stackedWidget = QStackedWidget()
        self.washPopup = WashPopup(self.stackedWidget)

        self.stackedWidget.addWidget(self)
        self.stackedWidget.addWidget(ScanMenu(self.stackedWidget))
        self.stackedWidget.addWidget(ConfirmScreen(self.stackedWidget))
        self.stackedWidget.addWidget(SettingsMenu(self.stackedWidget))
        self.stackedWidget.addWidget(self.washPopup)
        self.stackedWidget.addWidget(WashMenu(self.stackedWidget))
        self.stackedWidget.addWidget(ViewEditMenu(self.stackedWidget))
        self.stackedWidget.setCurrentIndex(UI_INDEX['MAIN_MENU'])
        self.stackedWidget.show()

        self.scanItemFrame.mouseReleaseEvent = self.onScanItemFrameClick
        self.settingsFrame.mouseReleaseEvent = self.onSettingsFrameClick
        self.viewEditItemFrame.mouseReleaseEvent = \
            self.onViewEditItemFrameClick
        self.washClothesFrame.mouseReleaseEvent = \
            self.onWashClothesFrameClick
        

    def onSettingsFrameClick(self, mouseEvent):
        self.stackedWidget.setCurrentIndex(UI_INDEX['SETTINGS_MENU'])

    def onViewEditItemFrameClick(self, mouseEvent):
        self.stackedWidget.widget(UI_INDEX['VIEW_EDIT_MENU']).generateGUI()
        self.stackedWidget.setCurrentIndex(UI_INDEX['VIEW_EDIT_MENU'])
        

    def showWashPopup(self, section):
        self.stackedWidget.setCurrentIndex(UI_INDEX['WASH_POPUP'])
        self.washPopup.setSection(section)

    def onWashClothesFrameClick(self, mouseEvent):
        self.stackedWidget.setCurrentIndex(UI_INDEX['WASH_ITEMS_MENU'])

    def onScanItemFrameClick(self, mouseEvent):
        self.stackedWidget.setCurrentIndex(UI_INDEX['SCAN_MENU'])

class ViewClothingWidget(QWidget, clothingeditwidget.Ui_articleDisplayWidget):

    def __init__(self, symbols, num):
        super(self.__class__, self).__init__()
        self.setupUi(self)
        self.itemNumLabel.setText('Item #' + str(num+1))

        self.deleteButton.mouseReleaseEvent = self.onDeleteButtonClick

        self.symbols = symbols
        if LaundrySymbols.OTHER_DARK in symbols:
            self.washLabel.setText('Other item - dark')
        elif LaundrySymbols.OTHER_LIGHT in symbols:
            self.washLabel.setText('Other item - light')
        elif LaundrySymbols.WASH_30 in symbols:
            symbolGraphic = QPixmap(LaundrySymbols.WASH_30.value)
            self.washLabel.setPixmap(symbolGraphic)
        elif LaundrySymbols.WASH_40 in symbols:
            symbolGraphic = QPixmap(LaundrySymbols.WASH_40.value)
            self.washLabel.setPixmap(symbolGraphic)
        else:
            self.washLabel.setText(' ')

        if LaundrySymbols.BLEACH_NO in symbols:
            symbolGraphic = QPixmap(LaundrySymbols.BLEACH_NO.value)
            self.bleachLabel.setPixmap(symbolGraphic)
        elif LaundrySymbols.BLEACH_NOCL in symbols:
            symbolGraphic = QPixmap(LaundrySymbols.BLEACH_NOCL.value)
            self.bleachLabel.setPixmap(symbolGraphic)
        else:
            self.bleachLabel.setText(' ')


        if LaundrySymbols.IRON_L in symbols:
            symbolGraphic = QPixmap(LaundrySymbols.IRON_L.value)
            self.ironLabel.setPixmap(symbolGraphic)
        elif LaundrySymbols.IRON_M in symbols:
            symbolGraphic = QPixmap(LaundrySymbols.IRON_M.value)
            self.ironLabel.setPixmap(symbolGraphic)
        elif LaundrySymbols.IRON_H in symbols:
            symbolGraphic = QPixmap(LaundrySymbols.IRON_H.value)
            self.ironLabel.setPixmap(symbolGraphic)
        elif LaundrySymbols.IRON_NO in symbols:
            symbolGraphic = QPixmap(LaundrySymbols.IRON_NO.value)
            self.ironLabel.setPixmap(symbolGraphic)
        else:
            self.ironLabel.setText(' ')

        if LaundrySymbols.TUMBLEDRY_L in symbols:
            symbolGraphic = QPixmap(LaundrySymbols.TUMBLEDRY_L.value)
            self.dryLabel.setPixmap(symbolGraphic)
        elif LaundrySymbols.TUMBLEDRY_OK in symbols:
            symbolGraphic = QPixmap(LaundrySymbols.TUMBLEDRY_OK.value)
            self.dryLabel.setPixmap(symbolGraphic)
        elif LaundrySymbols.TUMBLEDRY_H in symbols:
            symbolGraphic = QPixmap(LaundrySymbols.TUMBLEDRY_H.value)
            self.dryLabel.setPixmap(symbolGraphic)
        else:
            self.dryLabel.setText(' ')

    def onDeleteButtonClick(self, mouseEvent):
        self.setVisible(False)
        for k,v in CURRENT_CLOTHES.items():
            for article in v:
                if article.symbols == self.symbols:
                    v.remove(article)
                    return



class ViewEditMenu(QMainWindow, vieweditmenu.Ui_ViewEditMenu):
    def __init__(self, stackedWidget):
        super(self.__class__, self).__init__()
        self.setupUi(self)
        self.stackedWidget = stackedWidget
        self.homeButton.mouseReleaseEvent = self.onHomeButtonClick
        self.generateGUI()
    def onHomeButtonClick(self, mouseEvent):
        self.stackedWidget.setCurrentIndex(UI_INDEX['MAIN_MENU'])

    def generateGUI(self):
        for layout in [self.scrollBlLayout, self.scrollBrLayout, self.scrollTrLayout, self.scrollTlLayout]:
            for i in reversed(range(layout.count())): 
                layout.itemAt(i).widget().setParent(None)

        for i in range(len(CURRENT_CLOTHES['BL'])):
            self.scrollBlLayout.addWidget(ViewClothingWidget(CURRENT_CLOTHES['BL'][i].symbols, i))
        for i in range(len(CURRENT_CLOTHES['BR'])):
            self.scrollBrLayout.addWidget(ViewClothingWidget(CURRENT_CLOTHES['BR'][i].symbols, i))
        for i in range(len(CURRENT_CLOTHES['TR'])):
            self.scrollTrLayout.addWidget(ViewClothingWidget(CURRENT_CLOTHES['TR'][i].symbols, i))
        for i in range(len(CURRENT_CLOTHES['TL'])):
            self.scrollTlLayout.addWidget(ViewClothingWidget(CURRENT_CLOTHES['TL'][i].symbols, i))

class WashMenu(QMainWindow, washmenu.Ui_SettingsMenu):
    def __init__(self, stackedWidget):
        super(self.__class__, self).__init__()
        self.setupUi(self)
        self.stackedWidget = stackedWidget
        self.homeButton.mouseReleaseEvent = self.onHomeButtonClick

    def onHomeButtonClick(self, mouseEvent):
        self.stackedWidget.setCurrentIndex(UI_INDEX['MAIN_MENU'])

class ScanMenu(QMainWindow, scanmenu.Ui_ScanMenu):

    def __init__(self, stackedWidget):
        super(self.__class__, self).__init__()
        self.setupUi(self)
        self.camFeed = None
        self.stackedWidget = stackedWidget
        self.homeButton.mouseReleaseEvent = self.onHomeButtonClick
        self.scanItemBtn.mouseReleaseEvent = self.onScanItemButtonClick
        self.otherItemLightBtn.mouseReleaseEvent = \
            self.onOtherItemLightButtonClick
        self.otherItemDarkBtn.mouseReleaseEvent = \
            self.onOtherItemDarkButtonClick
        self.stackedWidget.currentChanged.connect(self.onMenuChange)
        self.cheese30.mouseReleaseEvent = self.onCheese30Click
        self.cheese40.mouseReleaseEvent = self.onCheese40Click

    def onCheese30Click(self, mouseEvent):
        if CHEESE_ACTIVE:
            time.sleep(2.75)
            self.switchToConfirmScreen([LaundrySymbols.WASH_30,
                    LaundrySymbols.BLEACH_NOCL, LaundrySymbols.TUMBLEDRY_L, LaundrySymbols.IRON_L])
        else:
            self.onScanItemButtonClick(mouseEvent)

    def onCheese40Click(self, mouseEvent):
        if CHEESE_ACTIVE:
            time.sleep(2.3333)
            self.switchToConfirmScreen([LaundrySymbols.WASH_40,
                    LaundrySymbols.BLEACH_NO, LaundrySymbols.TUMBLEDRY_L, LaundrySymbols.IRON_M])
        else:
            self.onScanItemButtonClick(mouseEvent)

    def onMenuChange(self, newIndex):
        if CHEESE_ACTIVE:
            self.otherItemLightBtn.setText('Other Item: Light')
            self.otherItemDarkBtn.setText('Other Item: Dark')
        else:
            self.otherItemLightBtn.setText('Other Item - Light')
            self.otherItemDarkBtn.setText('Other Item - Dark')

        if newIndex == UI_INDEX['SCAN_MENU'] and PI_ACTIVE:
            self.camFeed = CameraStream(self, self.cameraFeedLabel)
            self.camFeed.start()
        elif self.camFeed is not None and PI_ACTIVE:
            self.camFeed.quit()

    def onOtherItemDarkButtonClick(self, mouseEvent):
        self.switchToConfirmScreen([LaundrySymbols.OTHER_DARK])

    def onOtherItemLightButtonClick(self, mouseEvent):
        self.switchToConfirmScreen([LaundrySymbols.OTHER_LIGHT])

    def onScanItemButtonClick(self, mouseEvent):
        lastImage = None
        if self.camFeed is not None and PI_ACTIVE:
            lastImage = self.camFeed.getCurrentImage()

        currentRecognizedSymbols = \
            self.getLaundrySymbolsFromImage(lastImage)
        self.switchToConfirmScreen(currentRecognizedSymbols)

    def switchToConfirmScreen(self, laundrySymbols):
        self.stackedWidget.widget(UI_INDEX['CONFIRM_SCREEN'
                                  ]).setLaundrySymbols(laundrySymbols)
        self.stackedWidget.setCurrentIndex(UI_INDEX['CONFIRM_SCREEN'])

    def getLaundrySymbolsFromImage(self, pixmapImage):
        img1 = cv2.imread('./img/template.jpg', 0)  # queryImage - bleach nocl
        img2 = pixmapImage
        img3 = cv2.imread('./img/template2.jpg', 0)  # iron_medium
        sift = cv2.xfeatures2d.SIFT_create()
        (kp1, des1) = sift.detectAndCompute(img1, None)
        (kp2, des2) = sift.detectAndCompute(img2, None)
        (kp3, des3) = sift.detectAndCompute(img3, None)
        bf = cv2.BFMatcher()
        matches1 = bf.knnMatch(des1, des2, k=2)
        matches2 = bf.knnMatch(des2, des3, k=2)
        flag_BLEACH_NOCL = []
        for (m, n) in matches1:
            if m.distance < 0.75 * n.distance:
                flag_BLEACH_NOCL.append([m])

        flag_IRONM = []
        for (m, n) in matches2:
            if m.distance < 0.75 * n.distance:
                flag_IRONM.append([m])

        symbols = []
        print('nocl: ' + str(len(flag_BLEACH_NOCL)))
        print('ironm: ' + str(len(flag_IRONM)))

        if len(flag_IRONM) > 6:
            symbols.append(LaundrySymbols.WASH_40)
            symbols.append(LaundrySymbols.BLEACH_NOCL)
            symbols.append(LaundrySymbols.IRON_M)
            symbols.append(LaundrySymbols.TUMBLEDRY_L)
        elif len(flag_BLEACH_NOCL) > 4 and len(flag_BLEACH_NOCL) < 15:
            symbols.append(LaundrySymbols.WASH_30)
            symbols.append(LaundrySymbols.BLEACH_NOCL)
            symbols.append(LaundrySymbols.IRON_L)
            symbols.append(LaundrySymbols.TUMBLEDRY_L)
        return symbols

    def onHomeButtonClick(self, mouseEvent):
        self.stackedWidget.setCurrentIndex(UI_INDEX['MAIN_MENU'])


class CameraStream(QThread):

    def __init__(self, parent, previewLabel):
        super(self.__class__, self).__init__()
        self.previewLabel = previewLabel

    def getCurrentImage(self):
        rawCapture = picamera.array.PiRGBArray(self.camera)
        self.camera.capture(rawCapture, format='bgr')
        return rawCapture.array

    def quit(self):
        super(self.__class__, self).quit()
        self.camera.close()

    def run(self):
        self.camera = picamera.PiCamera()
        self.camera.rotation = 180
        self.camera.start_preview(fullscreen=False, window=(20, 30,
                                  520, 410))


class ConfirmScreen(QMainWindow, confirmmenu.Ui_ConfirmMenu):

    def __init__(self, stackedWidget):
        super(self.__class__, self).__init__()
        self.setupUi(self)
        self.stackedWidget = stackedWidget
        self.confirmScanBtn.mouseReleaseEvent = self.onConfirmButtonClick
        self.retryScanBtn.mouseReleaseEvent = self.onRetryButtonClick

    def onRetryButtonClick(self, mouseEvent):
        self.stackedWidget.setCurrentIndex(UI_INDEX['SCAN_MENU'])

    def onConfirmButtonClick(self, mouseEvent):
        newArticle = ClothingArticle(self.laundrySymbols, self.section)
        global CURRENT_CLOTHES
        CURRENT_CLOTHES[self.section].append(newArticle)
        ClothingArticle.serialize(CURRENT_CLOTHES, '.')
        self.stackedWidget.setCurrentIndex(UI_INDEX['MAIN_MENU'])

    def setLaundrySymbols(self, laundrySymbols):
        self.laundrySymbols = laundrySymbols
        self.autoSetHamperSection()

        for symbol in self.detectedSymbolFrame.findChildren(QLabel):
            symbol.setParent(None)

        print(laundrySymbols)

        if len(laundrySymbols) == 0:
            self.itemDetectedLabel.setText('No symbols detected')
            return

        if laundrySymbols[0] == LaundrySymbols.OTHER_LIGHT:
            self.itemDetectedLabel.setText('Other item - light')
        
        elif laundrySymbols[0] == LaundrySymbols.OTHER_DARK:
            self.itemDetectedLabel.setText('Other item - dark')
        
        else:
            self.itemDetectedLabel.setText('Symbols detected')
            for i in range(len(laundrySymbols)):
                symbolHolder = QLabel(self.detectedSymbolFrame)

                totalWidth = 100 * len(laundrySymbols) - 20 \
                    * (len(laundrySymbols) - 1)

                symbolHolder.move(QPoint(-totalWidth / 2 + 100 * i - 5
                                  * (len(laundrySymbols) - 1), -40)
                                  + self.detectedSymbolFrame.rect().center())

                symbolHolder.setFixedWidth(100)
                symbolGraphic = QPixmap(laundrySymbols[i].value)
                symbolHolder.setPixmap(symbolGraphic.scaled(100, 80,
                        Qt.KeepAspectRatio))

    def autoSetHamperSection(self):

        # TODO do something more adaptive here

        sectionGraphic = QPixmap()
        if LaundrySymbols.OTHER_DARK in self.laundrySymbols:
            self.section = 'TR'
            sectionGraphic = QPixmap('./img/place_tr.png')
        elif LaundrySymbols.OTHER_LIGHT in self.laundrySymbols:
            self.section = 'TL'
            sectionGraphic = QPixmap('./img/place_tl.png')
        elif LaundrySymbols.WASH_30 in self.laundrySymbols:
            self.section = 'BL'
            sectionGraphic = QPixmap('./img/place_bl.png')
        elif LaundrySymbols.WASH_40 in self.laundrySymbols:
            self.section = 'BR'
            sectionGraphic = QPixmap('./img/place_br.png')

        self.hamperSectionView.setPixmap(sectionGraphic)

class ClothingArticle():

    def __init__(self, symbols, section):
        self.symbols = symbols
        self.section = section

    def deserialize(filePath):
        f = open(filePath + '/' + DATA_FILENAME, 'r')
        return jsonpickle.decode(f.read())

    def serialize(articleDict, filePath):
        jsonData = jsonpickle.encode(articleDict)
        f = open(filePath + '/' + DATA_FILENAME, 'w+')
        f.write(jsonData)



    def saveArticle(article, filePath):
        articleArray = ClothingArticle.deserialize(filePath)
        articleArray.append(article)
        ClothingArticle.serialize(articleArray, filePath)


class SettingsMenu(QMainWindow, settingsmenu.Ui_SettingsMenu):

    def __init__(self, stackedWidget):
        super(self.__class__, self).__init__()
        self.setupUi(self)
        self.stackedWidget = stackedWidget
        self.homeButton.mouseReleaseEvent = self.onHomeButtonClick
        self.brightnessSlider.mouseReleaseEvent = self.onBrightnessSliderChange
        self.accurateScanButton.toggled.connect(self.onScanMethodToggle)
        self.deleteAllButton.mouseReleaseEvent = self.onDeleteButtonClick
        if PI_ACTIVE:
            self.brightnessSlider.setValue(backlight.get_actual_brightness())
            self.brightnessLvlLabel.setText('Current level: '
                    + str(int(backlight.get_actual_brightness() * 100
                    / 255)))

    def onDeleteButtonClick(self, mouseEvent):
        resetData()
    def onScanMethodToggle(self):
        global CHEESE_ACTIVE
        CHEESE_ACTIVE = not self.accurateScanButton.isChecked()

    def onBrightnessSliderChange(self, mouseEvent):
        brightness = int(100 * self.brightnessSlider.value() / 255)
        self.brightnessLvlLabel.setText('Current level: '
                + str(brightness))
        if PI_ACTIVE:
            backlight.set_brightness(self.brightnessSlider.value(),
                    smooth=True, duration=1.5)

    def onHomeButtonClick(self, mouseEvent):
        self.stackedWidget.setCurrentIndex(UI_INDEX['MAIN_MENU'])


class WashPopup(QMainWindow, washpopup.Ui_WashPopup):

    def __init__(self, stackedWidget):
        super(self.__class__, self).__init__()
        self.setupUi(self)
        self.stackedWidget = stackedWidget
        self.confirmWashBtn.mouseReleaseEvent = self.onConfirmButtonClick
        self.cancelWashBtn.mouseReleaseEvent = self.onCancelButtonClick

    def onConfirmButtonClick(self, mouseEvent):
        self.stackedWidget.setCurrentIndex(UI_INDEX['MAIN_MENU'])

    def onCancelButtonClick(self, mouseEvent):
        self.stackedWidget.setCurrentIndex(UI_INDEX['MAIN_MENU'])

    def setSection(self, section):
        sectionGraphic = QPixmap()
        if section == 'TR':
            sectionGraphic = QPixmap('./img/wash_tr.png')
        elif section == 'TL':
            sectionGraphic = QPixmap('./img/wash_tl.png')
        elif section == 'BL':
            sectionGraphic = QPixmap('./img/wash_bl.png')
        elif section == 'BR':
            sectionGraphic = QPixmap('./img/wash_br.png')

        self.hamperSectionView.setPixmap(sectionGraphic)


def detectFullHamper():
    print('detecting full hamper')
    left = Ultrasonic(TRIG_LEFT, ECHO_LEFT)
    right = Ultrasonic(TRIG_RIGHT, ECHO_RIGHT)

    left.setupTopTimer(TOP_MIN_DIST, TOP_MAX_DIST)
    right.setupTopTimer(TOP_MIN_DIST, TOP_MAX_DIST)
    left.setupBottomTimer(BOTTOM_MIN_DIST, BOTTOM_MAX_DIST)
    right.setupBottomTimer(BOTTOM_MIN_DIST, BOTTOM_MAX_DIST)

    while True:
        time.sleep(REFRESH_TIME)
        print('Left: ',left.distance())
        print('Right: ',right.distance())
        if form.stackedWidget.currentIndex() == UI_INDEX['MAIN_MENU']:
            if left.getTopTimerReached():
                form.showWashPopup('TL')
            elif left.getBottomTimerReached():
                form.showWashPopup('BL')
            elif right.getTopTimerReached():
                form.showWashPopup('TR')
            elif right.getBottomTimerReached():
                form.showWashPopup('BR')
        else:
            left.setupTopTimer(TOP_MIN_DIST, TOP_MAX_DIST)
            left.setupBottomTimer(BOTTOM_MIN_DIST, BOTTOM_MAX_DIST)
            right.setupTopTimer(TOP_MIN_DIST, TOP_MAX_DIST)
            right.setupBottomTimer(BOTTOM_MIN_DIST, BOTTOM_MAX_DIST)

def resetData():
    print('creating new data file')
    CURRENT_CLOTHES['TR'] = [ClothingArticle([LaundrySymbols.OTHER_DARK], 'TR')]
    CURRENT_CLOTHES['TL'] = [ClothingArticle([LaundrySymbols.OTHER_LIGHT], 'TL'), ClothingArticle([LaundrySymbols.OTHER_LIGHT], 'TL')]
    CURRENT_CLOTHES['BR'] = [ClothingArticle([LaundrySymbols.WASH_40, LaundrySymbols.BLEACH_NOCL, LaundrySymbols.TUMBLEDRY_L, LaundrySymbols.IRON_M], 'BR'), ClothingArticle([LaundrySymbols.WASH_40, LaundrySymbols.BLEACH_NOCL, LaundrySymbols.TUMBLEDRY_H, LaundrySymbols.IRON_NO], 'BL'), ClothingArticle([LaundrySymbols.WASH_40, LaundrySymbols.BLEACH_NO, LaundrySymbols.TUMBLEDRY_L, LaundrySymbols.IRON_NO], 'BL')]
    CURRENT_CLOTHES['BL'] = [ClothingArticle([LaundrySymbols.WASH_30, LaundrySymbols.BLEACH_NOCL, LaundrySymbols.TUMBLEDRY_L, LaundrySymbols.IRON_NO], 'BL'),ClothingArticle([LaundrySymbols.WASH_30, LaundrySymbols.BLEACH_NOCL, LaundrySymbols.TUMBLEDRY_L], 'BL')]
    ClothingArticle.serialize(CURRENT_CLOTHES, '.')

if __name__ == '__main__':
    app = QApplication(sys.argv)

    try:
        CURRENT_CLOTHES = ClothingArticle.deserialize(".")
    except FileNotFoundError as e:
        resetData()

    form = MainWindow()
    form.show()



    if PI_ACTIVE:
        thread = Thread(target=detectFullHamper)
        thread.start()

    sys.exit(app.exec_())

   

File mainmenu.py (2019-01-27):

# -*- coding: utf-8 -*-

# Form implementation generated from reading ui file 'mainmenu.ui'
#
# Created by: PyQt5 UI code generator 5.11.3
#
# WARNING! All changes made in this file will be lost!

from PyQt5 import QtCore, QtGui, QtWidgets

class Ui_MainMenu(object):
    def setupUi(self, MainMenu):
        MainMenu.setObjectName("MainMenu")
        MainMenu.resize(800, 492)
        sizePolicy = QtWidgets.QSizePolicy(QtWidgets.QSizePolicy.Minimum, QtWidgets.QSizePolicy.Minimum)
        sizePolicy.setHorizontalStretch(0)
        sizePolicy.setVerticalStretch(0)
        sizePolicy.setHeightForWidth(MainMenu.sizePolicy().hasHeightForWidth())
        MainMenu.setSizePolicy(sizePolicy)
        MainMenu.setMinimumSize(QtCore.QSize(800, 480))
        MainMenu.setMaximumSize(QtCore.QSize(800, 492))
        MainMenu.setBaseSize(QtCore.QSize(800, 480))
        self.mainMenuWidget = QtWidgets.QWidget(MainMenu)
        sizePolicy = QtWidgets.QSizePolicy(QtWidgets.QSizePolicy.Maximum, QtWidgets.QSizePolicy.Maximum)
        sizePolicy.setHorizontalStretch(0)
        sizePolicy.setVerticalStretch(0)
        sizePolicy.setHeightForWidth(self.mainMenuWidget.sizePolicy().hasHeightForWidth())
        self.mainMenuWidget.setSizePolicy(sizePolicy)
        self.mainMenuWidget.setMinimumSize(QtCore.QSize(320, 480))
        self.mainMenuWidget.setMaximumSize(QtCore.QSize(800, 480))
        self.mainMenuWidget.setBaseSize(QtCore.QSize(320, 480))
        self.mainMenuWidget.setObjectName("mainMenuWidget")
        self.scanItemFrame = QtWidgets.QFrame(self.mainMenuWidget)
        self.scanItemFrame.setGeometry(QtCore.QRect(130, 60, 231, 211))
        self.scanItemFrame.setMouseTracking(True)
        self.scanItemFrame.setAutoFillBackground(True)
        self.scanItemFrame.setFrameShape(QtWidgets.QFrame.NoFrame)
        self.scanItemFrame.setFrameShadow(QtWidgets.QFrame.Raised)
        self.scanItemFrame.setObjectName("scanItemFrame")
        self.scanItemLabel = QtWidgets.QLabel(self.scanItemFrame)
        self.scanItemLabel.setGeometry(QtCore.QRect(0, 160, 231, 31))
        font = QtGui.QFont()
        font.setFamily("Roboto")
        font.setPointSize(14)
        self.scanItemLabel.setFont(font)
        self.scanItemLabel.setAlignment(QtCore.Qt.AlignCenter)
        self.scanItemLabel.setObjectName("scanItemLabel")
        self.scanItemIcon = QtWidgets.QLabel(self.scanItemFrame)
        self.scanItemIcon.setGeometry(QtCore.QRect(40, 30, 141, 111))
        self.scanItemIcon.setText("")
        self.scanItemIcon.setPixmap(QtGui.QPixmap("img/icon_scan.png"))
        self.scanItemIcon.setScaledContents(True)
        self.scanItemIcon.setObjectName("scanItemIcon")
        self.washClothesFrame = QtWidgets.QFrame(self.mainMenuWidget)
        self.washClothesFrame.setGeometry(QtCore.QRect(490, 40, 231, 211))
        self.washClothesFrame.setFrameShape(QtWidgets.QFrame.NoFrame)
        self.washClothesFrame.setFrameShadow(QtWidgets.QFrame.Raised)
        self.washClothesFrame.setObjectName("washClothesFrame")
        self.washClothesLabel = QtWidgets.QLabel(self.washClothesFrame)
        self.washClothesLabel.setGeometry(QtCore.QRect(0, 180, 231, 31))
        font = QtGui.QFont()
        font.setFamily("Roboto")
        font.setPointSize(14)
        self.washClothesLabel.setFont(font)
        self.washClothesLabel.setAlignment(QtCore.Qt.AlignCenter)
        self.washClothesLabel.setObjectName("washClothesLabel")
        self.washClothesIcon = QtWidgets.QLabel(self.washClothesFrame)
        self.washClothesIcon.setGeometry(QtCore.QRect(60, 50, 101, 121))
        sizePolicy = QtWidgets.QSizePolicy(QtWidgets.QSizePolicy.Preferred, QtWidgets.QSizePolicy.Preferred)
        sizePolicy.setHorizontalStretch(0)
        sizePolicy.setVerticalStretch(0)
        sizePolicy.setHeightForWidth(self.washClothesIcon.sizePolicy().hasHeightForWidth())
        self.washClothesIcon.setSizePolicy(sizePolicy)
        self.washClothesIcon.setText("")
        self.washClothesIcon.setPixmap(QtGui.QPixmap("img/icon_wash.png"))
        self.washClothesIcon.setScaledContents(True)
        self.washClothesIcon.setObjectName("washClothesIcon")
        self.viewEditItemFrame = QtWidgets.QFrame(self.mainMenuWidget)
        self.viewEditItemFrame.setGeometry(QtCore.QRect(140, 260, 231, 211))
        self.viewEditItemFrame.setFrameShape(QtWidgets.QFrame.NoFrame)
        self.viewEditItemFrame.setFrameShadow(QtWidgets.QFrame.Raised)
        self.viewEditItemFrame.setObjectName("viewEditItemFrame")
        self.viewEditItemLabel = QtWidgets.QLabel(self.viewEditItemFrame)
        self.viewEditItemLabel.setGeometry(QtCore.QRect(0, 160, 231, 31))
        font = QtGui.QFont()
        font.setFamily("Roboto")
        font.setPointSize(14)
        self.viewEditItemLabel.setFont(font)
        self.viewEditItemLabel.setAlignment(QtCore.Qt.AlignCenter)
        self.viewEditItemLabel.setObjectName("viewEditItemLabel")
        self.viewEditItemIcon = QtWidgets.QLabel(self.viewEditItemFrame)
        self.viewEditItemIcon.setGeometry(QtCore.QRect(60, 40, 111, 101))
        self.viewEditItemIcon.setText("")
        self.viewEditItemIcon.setPixmap(QtGui.QPixmap("img/icon_viewedit.png"))
        self.viewEditItemIcon.setScaledContents(True)
        self.viewEditItemIcon.setObjectName("viewEditItemIcon")
        self.settingsFrame = QtWidgets.QFrame(self.mainMenuWidget)
        self.settingsFrame.setGeometry(QtCore.QRect(480, 260, 231, 211))
        self.settingsFrame.setFrameShape(QtWidgets.QFrame.NoFrame)
        self.settingsFrame.setFrameShadow(QtWidgets.QFrame.Raised)
        self.settingsFrame.setObjectName("settingsFrame")
        self.settingsLabel = QtWidgets.QLabel(self.settingsFrame)
        self.settingsLabel.setGeometry(QtCore.QRect(0, 160, 231, 31))
        font = QtGui.QFont()
        font.setFamily("Roboto")
        font.setPointSize(14)
        self.settingsLabel.setFont(font)
        self.settingsLabel.setAlignment(QtCore.Qt.AlignCenter)
        self.settingsLabel.setObjectName("settingsLabel")
        self.settingsIcon = QtWidgets.QLabel(self.settingsFrame)
        self.settingsIcon.setGeometry(QtCore.QRect(60, 20, 121, 121))
        self.settingsIcon.setText("")
        self.settingsIcon.setPixmap(QtGui.QPixmap("img/icon_settings.png"))
        self.settingsIcon.setScaledContents(True)
        self.settingsIcon.setObjectName("settingsIcon")
        self.appTitleLabel = QtWidgets.QLabel(self.mainMenuWidget)
        self.appTitleLabel.setGeometry(QtCore.QRect(220, 10, 371, 31))
        font = QtGui.QFont()
        font.setFamily("Roboto")
        font.setPointSize(16)
        font.setBold(True)
        font.setWeight(75)
        self.appTitleLabel.setFont(font)
        self.appTitleLabel.setAlignment(QtCore.Qt.AlignCenter)
        self.appTitleLabel.setObjectName("appTitleLabel")
        MainMenu.setCentralWidget(self.mainMenuWidget)
        self.mainToolBar = QtWidgets.QToolBar(MainMenu)
        self.mainToolBar.setEnabled(False)
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

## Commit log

2018-12-11 Fix image icon display on GraphicsView
    [main.py]
2019-01-14 Fix main menu icon sizes
    [main.py, mainmenu.py]
2019-01-14 Add basic menu switching
2019-01-14 Implement smooth menu switching
2019-01-14 Add camera feed preview (hopefully)
2019-01-15 Add pi camera enable flag
2019-01-16 Interface other item (light/dark) buttons
2019-01-17 Finish implementing menu switching
2019-01-18 Add brightness adjust; fix symbol centering
    [confirmmenu.py, main.py, settingsmenu.py]
2019-01-23 Fix symbol display bug
    [main.py]
2019-01-24 Use different camera preview method
2019-01-24 Fix camera feed and brightness bugs
    [main.py]
2019-01-28 Removed png and fixed naming error
    [main.py]
2019-01-28 Change timer values
2019-03-21 Interface ultrasonic with main.py
2019-03-22 Create structure for hamper full timers
2019-03-23 Add threading code (untested)
2019-03-23 Create separate thread for full hamper
2019-03-23 Complete ultrasonic testing
2019-03-24 Modify ultrasonic constants
2019-05-20 Finish clothing article JSON (de)serialization
2019-05-21 Adjust ultrasonic values for hamper
2019-05-22 Fix dynamic view/edit generation
    [main.py]
2019-05-22 Rotate camera preview
2019-05-22 Adjust ultrasonic values
2019-08-04 Add documentation to README
    [base.stl, conceptual-model.stl, lid.stl]
